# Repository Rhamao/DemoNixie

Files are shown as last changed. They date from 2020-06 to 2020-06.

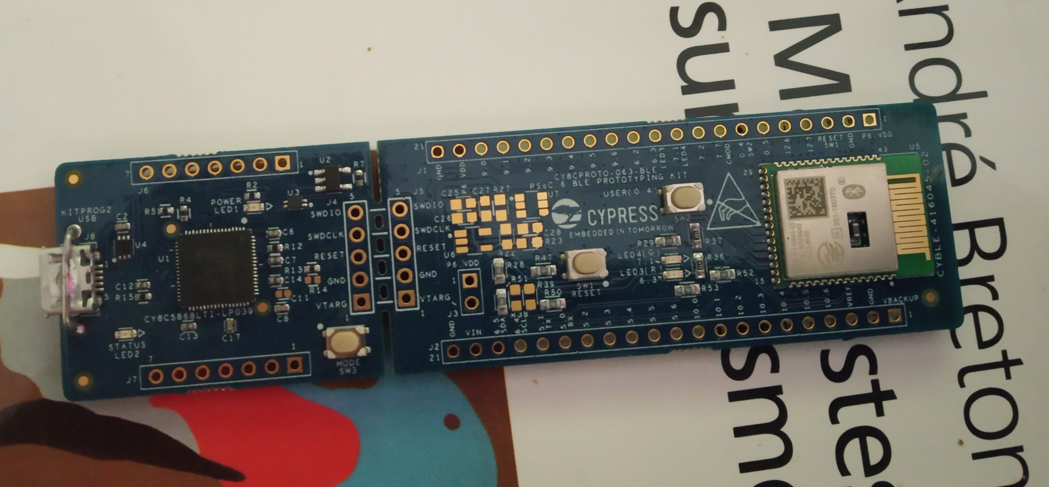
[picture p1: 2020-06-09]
images/CYBLEphoto.jpg

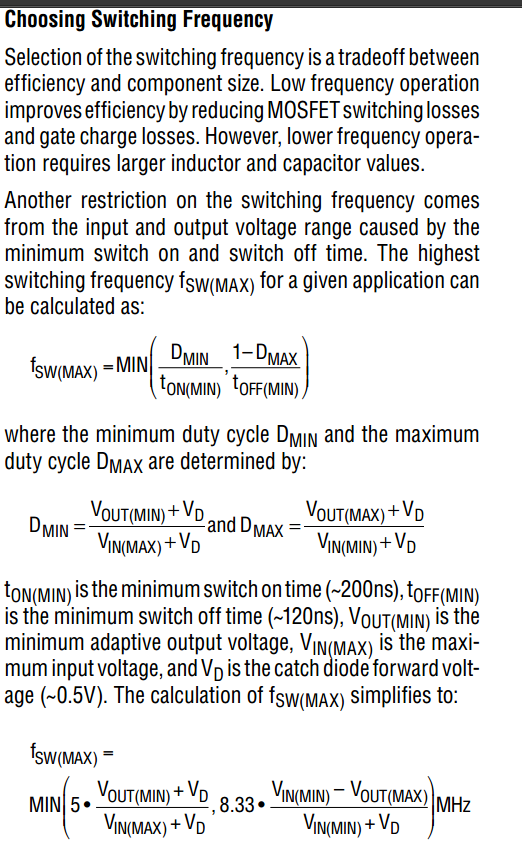
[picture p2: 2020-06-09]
images/Screenshot from 2020-05-18 19-58-37.png

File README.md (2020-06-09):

# DemoNixie
Projet LRPO MECSE de l'IUT de Cachan : Réalisation d'un démonstrateur nixie avec des leds

Branche contenant les documents relatifs à la conception électronique du projet.

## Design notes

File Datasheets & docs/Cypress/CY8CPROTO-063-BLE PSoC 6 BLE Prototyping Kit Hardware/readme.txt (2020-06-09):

--------------------------------------
PCB: 600-60527-01 Rev: 03 
--------------------------------------

PCB Name: CY8CPROTO-063-BLE PSoC 6 BLE PROT0 KIT 

PCB P/N: 600-60527-01 

PCB Rev.: 03 

---------------------------------
----------- PCB Info ------------
---------------------------------

PCB Size: 4.025" x 1.052" 

Layer Count: 2 

Minimum O/L Line Width: 5.010 
Minimum O/L Spacing:    4.990 

Minimum I/L Line Width: N/A 
Minimum I/L Spacing:    N/A 

BGA PIN Pitch: No Devices found. 

Non-BGA Pin Pitch MM (Minimum): 0.400 (Mils: 15.740) 
Non-BGA Reference Designator: U1 / Pins: 63-62 / Pin Count: 71 
Non-BGA Location: (284.7 400.0) - Top Side 

Silkscreen Layers: 2 

---------------------------------
---------- Drill Info -----------
---------------------------------

Number of Different Hole Sizes: 7 

Smallest Hole Size: 0.008 

Largest Hole Size: 0.040 

Hole Count: 433 

Blind-Buried Vias: No 

Slots Found: Yes 

---------------------------------
---------- Extra Info -----------
---------------------------------

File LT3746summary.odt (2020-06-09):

LT3746

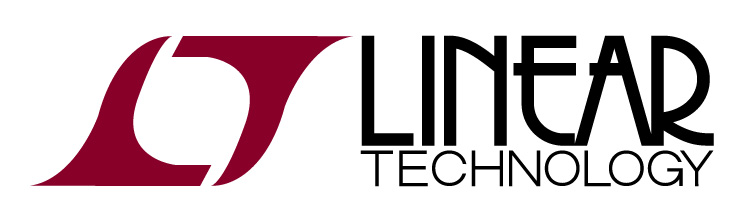
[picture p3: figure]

Features

- Tension d’alimentation de 3V à 5.5V, tension d’alim des LEDs de 6V à 55V
- 32 sorties LEDs indépendantes (10mA to 30mA)
- QFN package
- Registre à décalage de 386 bits

Typical application

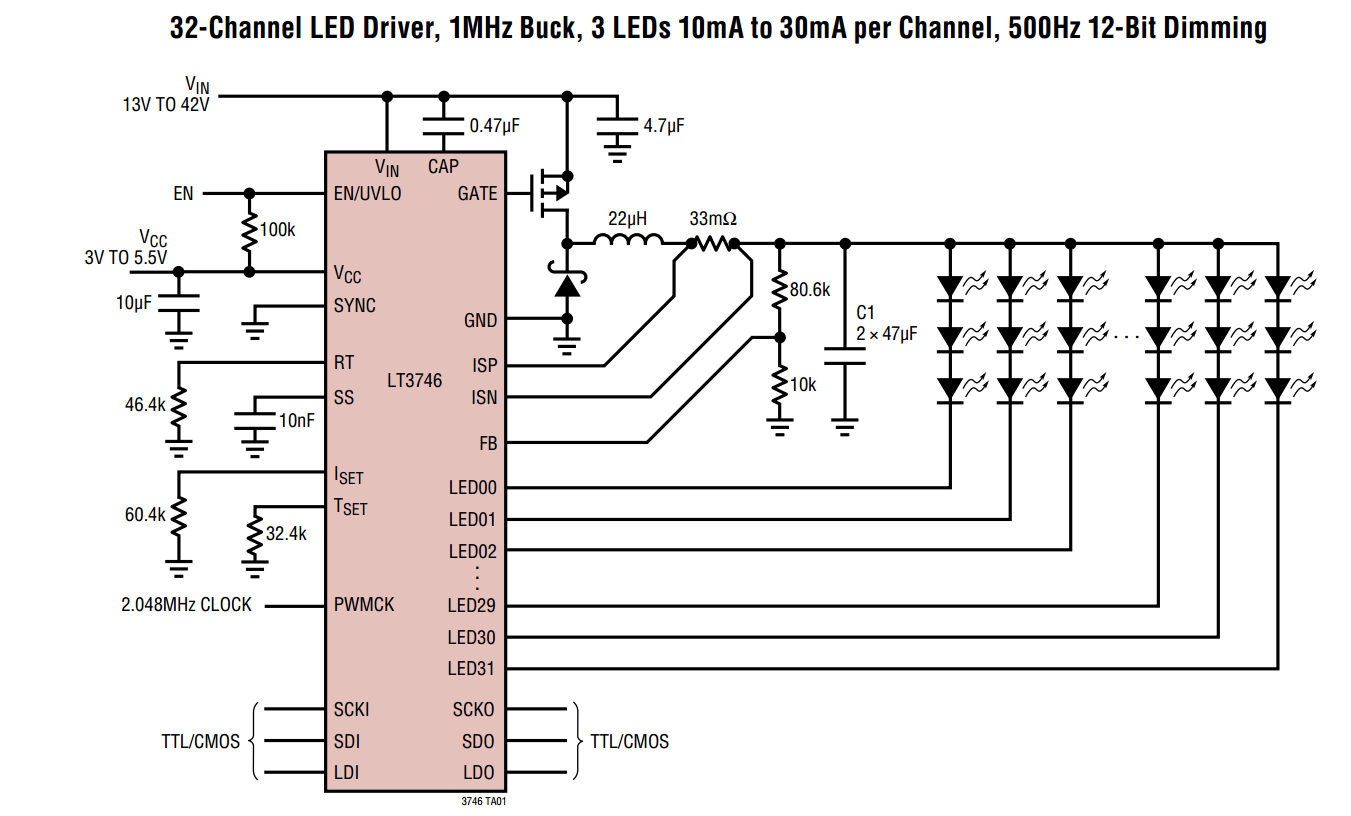
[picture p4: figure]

Pin functions

EN/UVLO : pin 1, enable pin, actif à l’état haut. Connecter à Vcc pour activer le composant, connecter à la masse (ou une tension inférieure à 0.35V) pour le désactiver. Cette pin sert également à définir l’UVLO du composant (seuil de tension d’alim minimum) via un pont diviseur, relié à Vcc. Utile en cas d’utilisation avec une batterie.

LED00 – LED31 : pin 2-17, 30-45. Sorties drivers, connecter aux cathodes des LEDs.

GND : pin 18, 20, 27, 29. Masse.

SCKI : pin19. Entrée clock pour l’interface série TTL/CMOS.

SDI : pin 21. Entrée data pour l’interface série TTL/CMOS.

LDI : pin 22. Entrée latch pour les registres à décalage. Met à jour les sorties en fonction de l’état des registres. Voir partie Opération de la datasheet (page 13).

Vcc : pin 23 : entrée alimentation de la partie logique.

PWMCK : pin 24. Clock pour le timer chargé de créer la PWM (gestion de la luminosité).

LDO : pin 25. Sortie latch pour chaîner un autre LT3746.

SDO : pin 25. Sortie série data pour chaîner un autre LT3746.

LDO : pin 25. Sortie seŕie clock pour chaîner un autre LT3746.

SYNC : pin 46. Une clock (TTL/CMOS) peut être reliée à cette entrée pour synchroniser la fréquence de découpage avec une clock externe. Relier à Vcc ou à la masse si elle n’est pas utiliser.

RT : pin 47, timing resistor. Programme la fréquence de découpage de 200kHz à 1MHz. Voir le Table 2 de la datasheet pour le calcul des valeurs.

SS : pin 48, soft start. Connecter un condensateur à cette entrée pour définir la durée du soft start afin de limiter le courant d’appel à l’allumage.

FB : pin 49, feedback pin. J’ai pas exactement compris comment ça marche, mais il faut la connecter à un pont diviseur entre la source du MOSFET et la masse, afin de réguler la tension d’alim des LEDs. Voir la partie Application Information de la datasheet (p19)

ISN : pin 50. Cette broche est connectée à une des terminaisons de la résistance de mesure du courant, côté négatif.

ISP : pin 51. Cette broche est connectée à l’autre terminaison de la résistance de mesure du courant, côté positif.

CAP : pin 52. Doit être reliée à Vin via un condensateur. J’ai pas exactement compris comment ça marche, mais ça participe à la régulation de la tension d’alim des LEDs. Condensateur près de la broche.

GATE : pin 53. Connecter à la gate du MOSFET avec une trace la plus courte et épaisse possible. Courant crête typique : 1A.

Vin : pin 54, entrée tension LED. Reliée à la masse par un condensateur de filtrage, près du MOSFET (?)

Tset : pin 55. Réglage du seuil de surchauffe. Voir la section Application Information de la datasheet (p19)

Iset : pin 56. Reglage du courant d’alimentation des LEDs via une résistance à la masse. Voir section Application Information (p19) de la datasheet.

Pad sous le composant : masse. Doit être connecté à un plan de masse continue (pas juste sous le pad) afin d’améliorer la dissipation thermique et augmenter la « power capability » du composant.

Interface série

4 Wire Topology :

- LDI, SCKI : global routing (commun a tous les composants)
- SDI : local routing (propre à chaque composant)
- SDI peut etre transmis de composant à composant via la broche SDO
- Peu de composant en cascades (décalage de l’horloge par rapport aux données série)

6 Wire Topology :

- SDI, SCKI, LDI sont envoyés au premier composant de la chaîne, qui les transmet au suivant etc...
- LDO, SCKO, SDO du dernier composant reviennent au uC (pourquoi?)

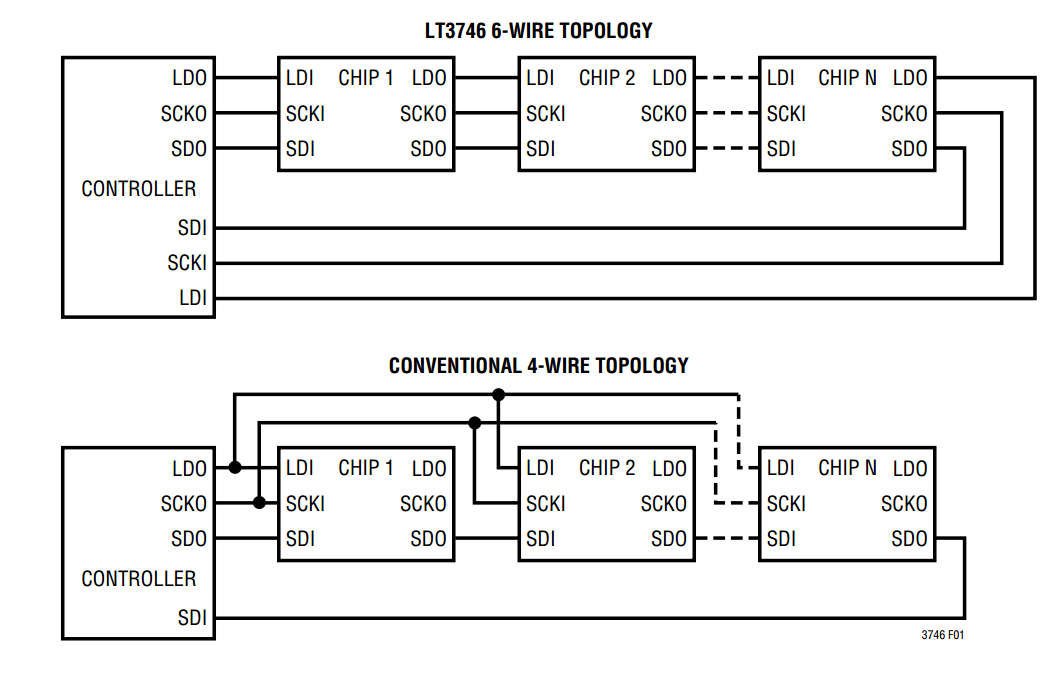
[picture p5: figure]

Les informations sont envoyées au composant sous la forme d’une trame de 386 bits (32 sous-trames de 12 bits + 2 bit de config générale). Cette trame est chargée dans un registre à décalage (SR[0:385]). Une fois les 386 bits envoyés (à chaque front montant de l’horloge sur SCKI), un front montant sur LDI charge les données dans les registres correspondant, et charge une trame de Status dans le registre à décalage de sortie. Si 4 composants sont chainés, il faut envoyer 4 trames de 386 bits. La trame de statut sera reçue avec 4 trames de retard (elle traverse chaque composant en cascade avant de passer au contrôleur).

Configuration analogique

Vout max : RFB1 et RFB2

Le pont diviseur connecté à la broche FB permet de fixer la tension maximale générée par le convertisseur Buck. La datasheet indique que cette tension devrait se situer à 0.5V au dessus de la chute de tension max des séries de LED :

V_{OUT(MAX)} = 0.5 + n times V_{F(MAX)}

Où n × VF(MAX) correspond à la chute de tension totale de la branche de LED avec la chute de tension la plus élevée. La datasheet des LED indique que la chute de tension directe de la LED bleue est de 3.3V max. Cela fait donc une tension VOUT(MAX) = 10.4V.

Les résistances du pont diviseur se calculent comme ceci :

R_FB2 = R_FB1 .( {V_{OUT(MAX)}} over {1.205V} -1)

On choisit une valeur arbitraire pour RFB1, et on détermine RFB2. La datasheet indique que la tolérance des résistance doit être la plus faible possible (1% recommandé), et que de très hautes valeurs de résistances peuvent entraîner des erreurs (RFB1 = 10kΩ recommandé).

Dans notre cas, avec VOUT(MAX) = 10.4V, on obtient ces valeurs : RFB1 = 10kΩ ; RFB2 = 76.307kΩ

Plage de tension d’entrée Vin

La tension d’entrée du convertisseur Buck peut varier entre 6V et 55V. Cependant, elle doit respecter la formule suivante afin de garantir un fonctionnement optimal :

V_{"IN"(MIN)} = V_{OUT(MAX)} + 2V

La tension d’alimentation du convertisseur Buck doit donc être de VIN(MAX) = 12.4V minimum.

Choix du courant nominal des LEDs : RISET

Le courant nominal correspond au courant qui circule dans chaque branche de LEDs lorsque la « dot correction » est programmée à 0x20 (*1). Les LEDs utilisées sont données pour un courant direct recommandé de 5mA (sauf pour la rouge, 10mA). Le courant nominal se calcul ainsi :

I_{LED(NOM)} = {V_ISET} over {R_ISET} * 1000

Avec une valeur RISET = 270kΩ, on a ISET = 4.46mA, ce qui laisse une petite marge de sécurité (le courant peut être ajusté via le registre Dot Correction).

Protection thermique (résistance TTSET)

Cette résistance détermine la tension VTSET. Cette tension est comparée avec une tension générée en interne, VPTAT, qui, lorsqu’elle est supérieure à VTSET, déclenche la protection thermique. Je n’ai pas vraiment compris tous les paramètres qui entre dans l’équation (principalement le calcul de TJ), mais il semblerai qu’une bonne valeur pour VTSET soit de 1V.

V_TSET = 1.205V × {R_{TSET}} over {R_{ISET}}

En choisissant une valeur de 240kΩ pour RTSET, on à VTSET = 1,07V.

Page 24 de la datasheet

Fréquence de découpage

La fréquence de découpage du convertisseur buck peut-être réglée entre 200kHz et 1MHz. Une fréquence basse améliore le rendement du montage en réduisant les pertes induite par le découpage et les cycles charges/décharges de la gate du MOSFET, mais implique de devoir utiliser des composants de plus grandes valeurs, donc plus large (inductance, condensateur) pour le convertisseur.

La résistance qui détermine la fréquence interne doit être choisie pour donner une fréquence environ 20 % en dessous de la fréquence de synchronisation, lorsque celle-ci est utilisée, ce qui est recommandé.

Si on choisit une fréquence de découpage de 500kHz, il faut une fréquence interne aux alentours de 400kHz. La datasheet indique une résistance de 133kΩ pour une fréquence de 400kHz.

Rappel des valeurs choisies

VIN(MIN) = 12.4V

VOUT(MAX) = 10.4V

RISET = 270kΩ

RTSET = 240kΩ

RS = 33mΩ

RFB1 = 10kΩ ; RFB2 = 76.307kΩ

Questions pour Claude

- J’ai un peu du mal à estimer l’importance de la valeur choisie pour la fréquence de découpage du convertisseur buck (configurée via la résistance RT). Est-ce que l’on peut choisir une valeur de 400kHz par exemple en étant sur que cela fonctionnera dans notre application ? Le schéma d’exemple fourni par LT (pas celui de la datasheet, celui qui est sur un PDF a part entière) choisi cette fréquence.

- Il est également question de synchroniser cette fréquence de découpage, mais je ne comprends pas à quoi ça sert. Sur le schéma d’exemple, la synchronisation se fait sur l’horloge de la PWM, ou via le microcontrôleur. Est-on obligé de le faire ? Peut-on sync sur l’horloge PWM sans risque ?

- Je me perd un peu dans le choix des composants pour le convertisseur buck. Est-ce que je peux choisir les même composants que sur le schéma d’exemple. Ça concerne le MOSFET, la diode, l’inductance et quelques condensateurs. Sachant qu’a priori on aura une tension d’alim de 15V (selon les calculs plus haut il faut une tension minimale de 12.4V).

- Quand j’ai choisi d’utiliser ce composant, je pensais que la fin du projet était pour début septembre (la fin de la formation) et qu’on aurait du temps pour approfondir l’usage du truc et faire des prototypes, tests. Finalement la soutenance est le 26 juin… Cela remet en perspective l’usage d’un composant aussi lourd. Il est super et je pense pas que ça soit extrêmement complexe à utiliser, mais disons qu’il y a pas mal de sources d’erreur et que je ne suis pas sur qu’on ai le temps de faire les tests nécessaires. Alors qu’en utilisant une batterie de shift registers on est sur de pas se planter, même si ça complique un peu le routage. En gros, est-ce que tu penses que c’est faisable dans les temps ? J’en doute un peu, et de plus en plus a mesure que je vois le travail qu’il reste à faire.

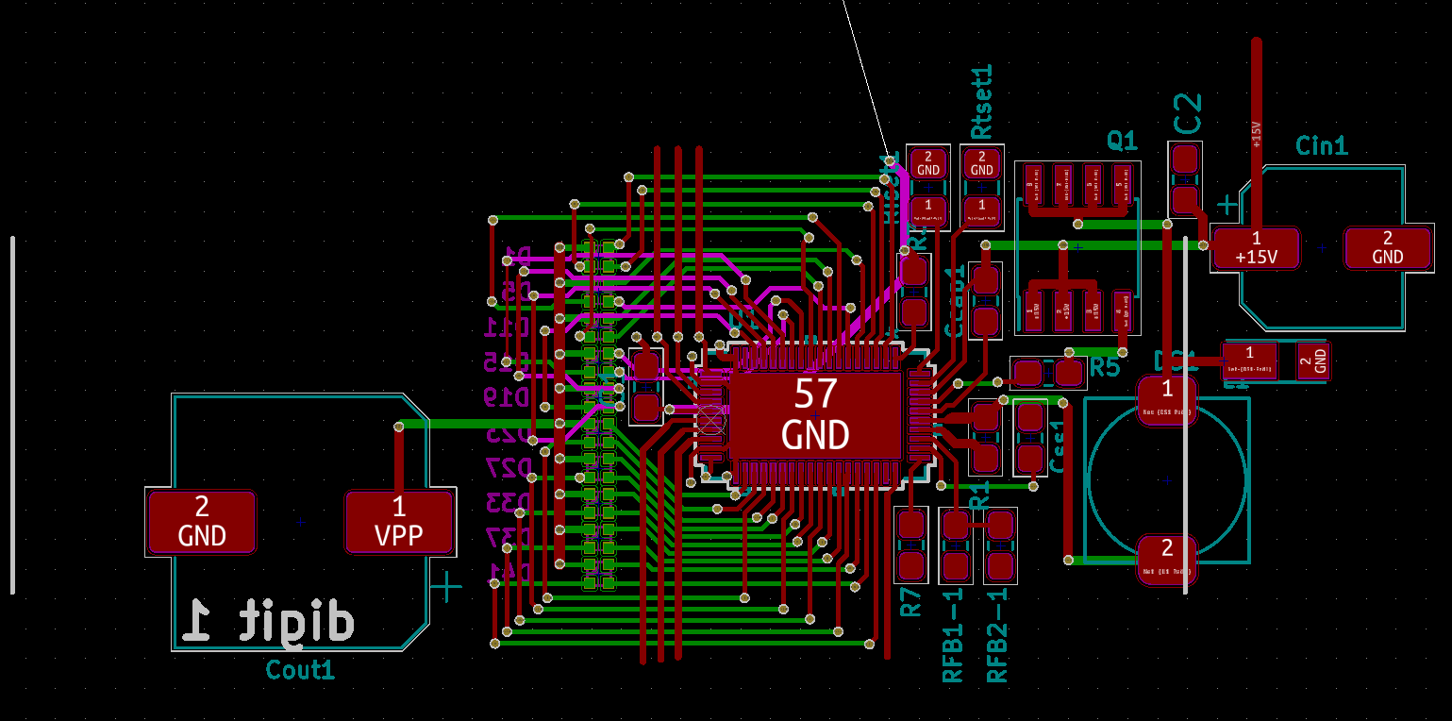
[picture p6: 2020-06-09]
DemoNixie-KiCad/images/Screenshot from 2020-06-03 17-18-07.png

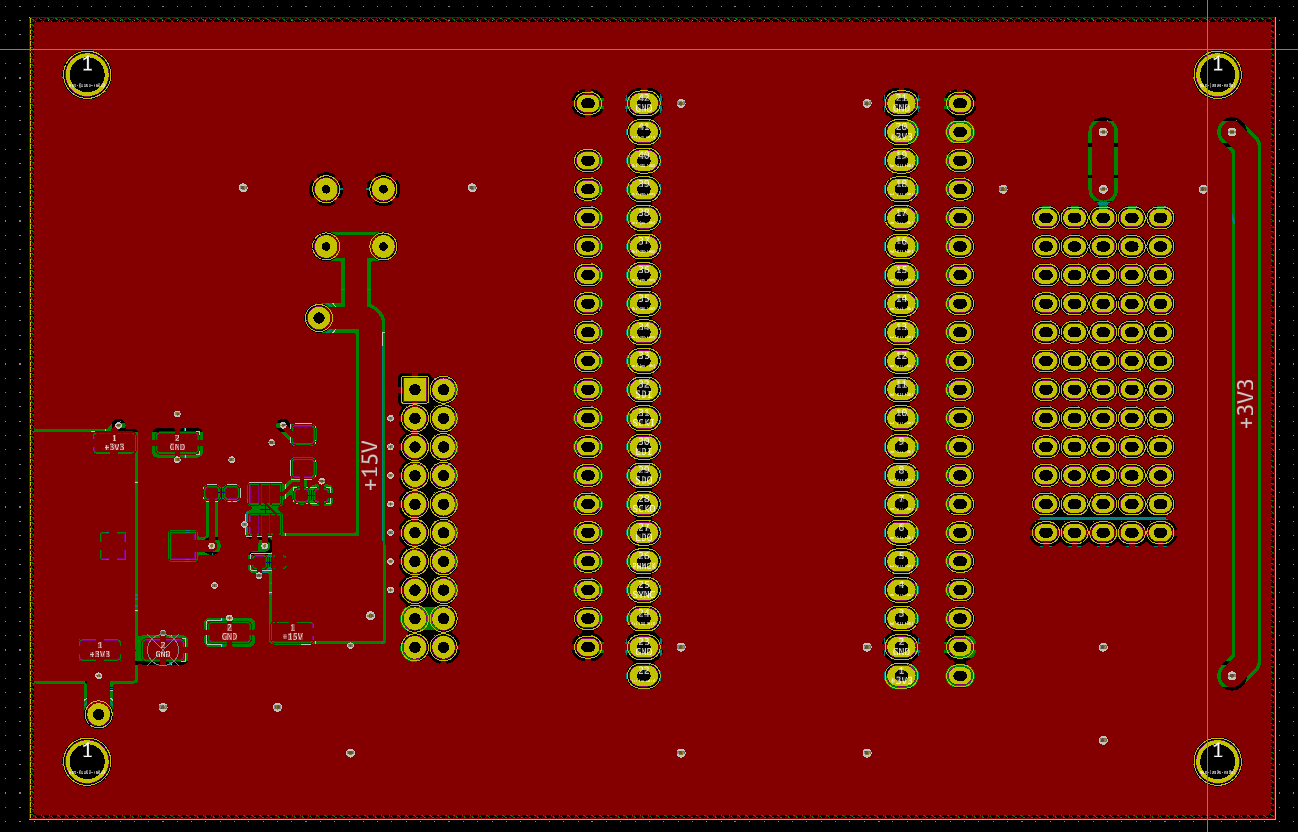
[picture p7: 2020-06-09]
DemoNixieControl-KiCad/images/masseTOP.png

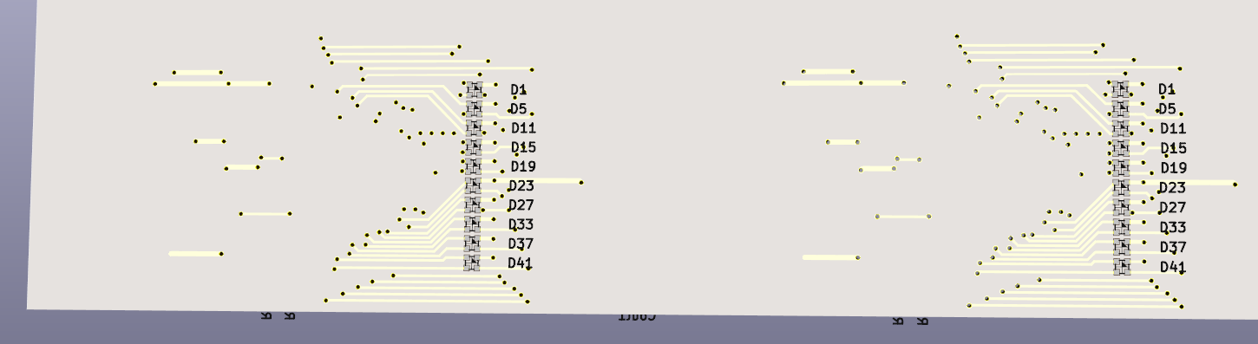
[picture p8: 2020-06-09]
DemoNixie-KiCad/images/Screenshot from 2020-06-03 17-16-41.png

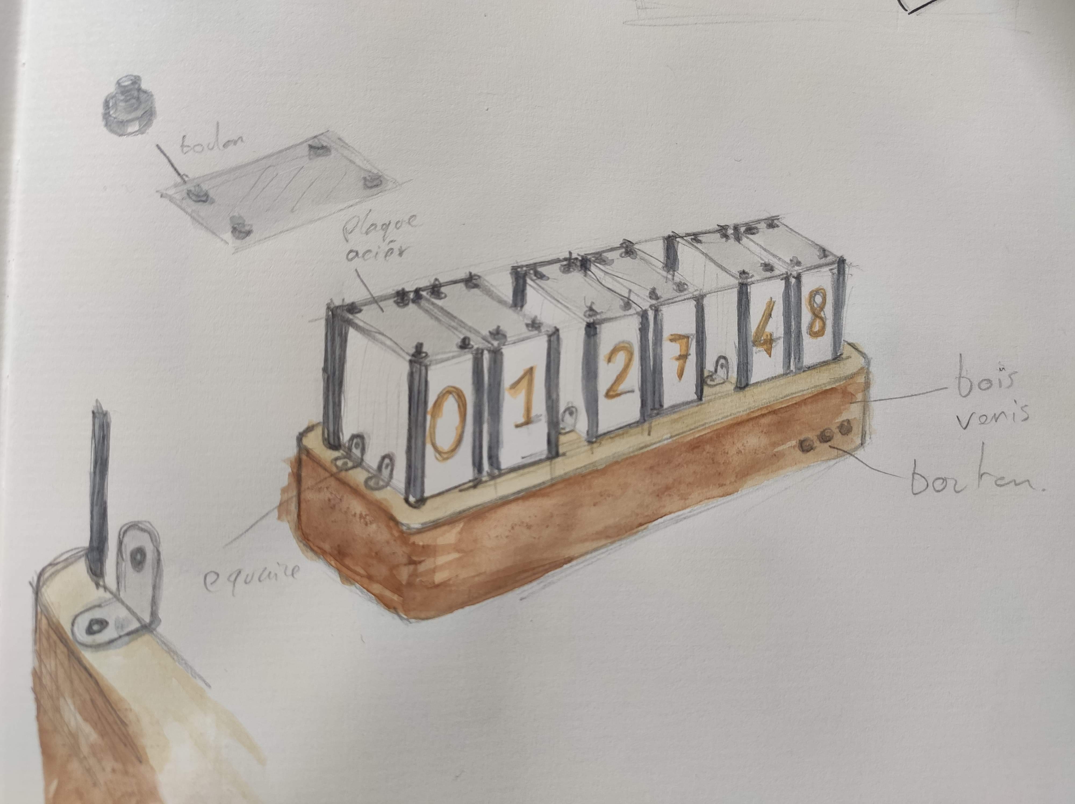
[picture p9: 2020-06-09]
images/dessinFrancois.jpg

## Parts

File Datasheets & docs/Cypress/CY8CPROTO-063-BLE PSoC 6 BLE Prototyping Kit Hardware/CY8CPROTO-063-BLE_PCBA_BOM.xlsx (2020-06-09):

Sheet: Revision History
CYPRESS SEMICONDUCTOR © 2017
Revision | Date | Description | Prepared By | Approved By
1 | 2018-06-02 | Initial BOM update | TARE | RKAD
2 | 2018-08-17 | updated to rev 02 | TARE | RKAD
3 | 2018-09-26 | rev 03 release, changed resistor R36 to 0603 | TARE | RKAD
4 | 2020-01-16 | Updated both WCO load caps C36,C37 to 22pF | TARE | RKAD
 |  |  |  |  | a

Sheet: PCBA BOM
 |  |  |  |  | CYPRESS SEMICONDUCTOR © 2017
 |  |  |  |  | TITLE | CY8CPROTO-063-BLE PSoC 6 BLE Prototyping Kit
 |  |  |  |  | PCBA Number & Revision | 121-60527-01 | Rev 03
 |  |  |  |  | Schematics Number & Revision | 630-60527-01 | Rev 04
 |  |  |  |  | DATE | 2020-01-16
 |  |  |  |  | BOM REVISION | Rev 04
 |  |  |  |  | ROHS Compliance | Required
 |  |  |  |  | UL Compliance | Required
# | Cypress Part # | Qty | Reference | Value | Description | Manufacturer | Mfr Part # | Alternate Manufacturer | Alternate Mfr Part #
1 | 510-60089-01 | 1 | C1 | 10nF | CAP, CER, 0.01uF, 10%, X7R, 50V, 0402 | Murata | GRM155R71H103KA88D
2 | 510-60247-01 | 11 | C2,C4,C6,C8,C10,C15,C17,C19,C21,C23,C38 | 0.1uF | CAP, CER, 0.1UF, 10%, X7R, 16V, 0402 | Samsung Electro-Mechanics America, Inc. | CL05B104KO5NNNC
3 | 510-60203-01 | 10 | C3,C5,C7,C9,C12,C13,C14,C16,C18,C20 | 1.0 uF | CAP, CER, 1UF, 10%, 10V, X5R, 0402 | Taiyo Yuden | LMK105BJ105KV-F
4 | 510-60058-01 | 2 | C22,C24 | 4.7uF | CAP, CER, 4.7uF, 10%, X5R, 16V, 0603 | Murata | GRM188R61C475KAAJD
5 | 510-60180-01 | 1 | C29 | 10uF | CAP, CER, 10uF, 20%, X5R, 25V, 0603 | Murata | GRM188R61E106MA73D
6 | 510-60190-01 | 1 | C32 | 2.2nF | CAP CER 2200PF 50V NP0 0805 | Murata | GRM2165C1H222JA01D
7 | 510-60716-01 | 2 | C36,C37 | 22pF | CAP, CER, 22PF, 5%, COG, 50V, 0402 | Yageo | CC0402JRNPO9BN220
8 | 751-60031-01 | 1 | JMP1 | USB_Hold | WIRE, WIRE BUS BAR 1000' LONG, THICKNESS 22 AWG | Alpha Wire | 298SV001
9 | 720-60080-01 | 1 | J8 | 10118194-0001LF | CONN, RCPT, STD, MICRO, USB, TYPE B | FCI | 10118194-0001LF
10 | 534-60113-01 | 2 | LED1,LED2 | AMBER LED | LED, YELLOW, CLEAR, 0603 | Lite-On Inc. | LTST-C191KSKT
11 | 534-60065-01 | 1 | LED3 | RED LED | LED, RED, CLEAR, 0603 | Lite-On Inc. | LTST-C190CKT
12 | 534-60054-01 | 1 | LED4 | GREEN LED | LED, GREEN, CLEAR, 0603 | Lite-On Inc | LTST-C190KGKT
13 | 500-60075-01 | 1 | R1 | 100K | RES, 100K OHM, 5%, 100PPM, 1/16W, 0402 | Yageo | RC0402JR-07100KL
14 | 500-60047-01 | 2 | R2,R17 | 2.2K | RES, 2.2K OHM, 5%, 200PPM, 1/10W, 0402 | Panasonic | ERJ-2GEJ222X
15 | 500-60108-01 | 11 | R3,R28,R29,R31,R47,R48,R49,R50,R51,R52,R53 | 0ohm | RES, 0 OHM, 1/10W, 0603, SMD | Rohm Semiconductor | MCR03EZPJ000
16 | 500-60445-01 | 2 | R4,R15 | 15K | RES, 15K OHM, 1/10W, 5%, 0402, SMD | Panasonic | ERJ-2GEJ153X
17 | 500-60446-01 | 2 | R5,R16 | 30K | RES, 30K OHM, 1/10W, 5%, 0402, SMD | Panasonic | ERJ-2GEJ303X
18 | 500-60925-01 | 1 | R6 | 180K | RES, 180K OHM, 1%, 100PPM, 1/10W, 0603 | Yageo | RC0603FR-07180KL
19 | 500-60926-01 | 1 | R7 | 57.6K | RES, 57.6K OHM, 1%, 100PPM, 1/16W, 0402, SMD | Yageo | RC0402FR-0757K6L
20 | 500-60927-01 | 1 | R8 | 383K | RES, 383K OHM, 1%, 100PPM, 1/16W, 0402 | Yageo | RC0402FR-07383KL
21 | 500-60075-01 | 1 | R12 | 100K | RES, 100K OHM, 5%, 200PPM, 1/10W, 0402 | Panasonic | ERJ-2GEJ104X
22 | 500-60149-01 | 1 | R13 | 49.9K | RES, 49.9K OHM, 1%, 100PPM, 1/10W, 0402, SMD | Panasonic | ERJ-2RKF4992X
23 | 500-60085-01 | 2 | R18,R19 | 22E | RES, 22 OHM, 1%, 100PPM, 1/16W, 0402 | Yageo | RC0402FR-0722RL
24 | 500-60095-01 | 2 | R20,R21 | 4.7K | RES, 4.7K OHM, 5%, 100PPM, 1/16W, 0402 | Yageo | RC0402JR-074K7L
25 | 500-60045-01 | 1 | R33 | 10K | RES, 10K OHM, 1/10W, 5%, 0603, SMD | Yageo | RC0603JR-0710KL
26 | 500-60589-01 | 1 | R36 | 470ohm | RES, 470 OHM, 5%, 1/10W, 0603, SMD | Panasonic | ERJ-3GEYJ474V
27 | 500-60129-01 | 1 | R37 | 330ohm | RES, 330 OHM, 5%, 200PPM, 1/10W, 0603 | Bourns Inc. | CR0603-JW-331GLF
28 | 500-60929-01 | 1 | R40 | 120K | RES, 120K OHM, 1%, 100PPM, 1/16W, 0402 | Yageo | RC0402FR-07120KL
29 | 770-60033-01 | 3 | SW1,SW2,SW3 | SKRPACE010 | SW, TACTILE SWITCH, 4.2x3.2x2.5MM, 260GF | ALPS ELECTRIC CO.,LTD | SKRPACE010
30 | CY8C5868LTI-LP039 | 1 | U1 | CY8C5868LTI-LP039 | IC, CYPRESS, PSoC 5LP, RAM 64KB, 32 Bit MCU, 68PIN, QFN | Cypress Semiconductor | CY8C5868LTI-LP039
31 | 450-60294-01 | 1 | U2 | AP7365-WG-7 | IC, REG, LDO, 600mA, ADJ, SOT25-5 | Diodes Incorporated | AP7365-WG-7
32 | 450-60257-01 | 1 | U3 | SiP32408 | IC, LOAD SWITCH, 3.5A, TDFN4 | Vishay Siliconix | SIP32408DNP-T1-GE4
33 | 530-60071-01 | 1 | U4 | PUSBM12VX4-TL,115 | TVS DIODE, 5.5VWM, 12VC, 6DFN1616 | NXP Semiconductors | PUSBM12VX4-TL,115
34 | CYBLE-416045-02 | 1 | U5 | CYBLE-416045-02 | BLE CHIP | Cypress Semiconductor | CYBLE-416045-02
35 | 455-60032-01 | 1 | U8 | AP2331TDW-7 | IC, CURRENT SW, 400mA, SC-59 | Diodes Incorporated | AP2331TDW-7
36 | 542-60016-01 | 1 | Y2 | 32.768KHz | CRYSTAL, 32.768KHZ, 12.5PF, SMD | ECS Inc | ECS-.327-12.5-34B-TR
NO LOAD
37 | 510-60203-01 | 1 | C11 | 1.0 uF | CAP, CER, 1UF, 10%, 10V, X5R, 0402 | Taiyo Yuden | LMK105BJ105KV-F
38 | 510-60284-01 | 2 | C25,C27 | 4.7uF | CAP, CER, 4.7uF, 10%, 10V, X5R, 0603 | Samsung Electro-Mechanics | CL10A475KP8NNNC
39 | 510-60279-01 | 2 | C26,C28 | 0.1uF | CAP, CER, 0.1UF, 10%, X7R, 16V, 0603 | Murata | GCM188R71C104KA37D
40 | 510-60417-01 | 2 | C30,C31 | 0.47nF | CAP CER 470PF 50V 5% NP0 0805 | Murata Electronics | GRM2165C1H471JA01D
41 | 510-60714-01 | 2 | C34,C35 | 10pF | CAP, CER, 10pF, 50V, ±0.5pF, C0G, NP0, 0603 | TDK Corporation | CGA3E2C0G1H100D080AA
42 |  | 2 | J1,J2 | CON 21x1 | CONN HEADER VERT 21POS .100 | Harwin Inc. | M20-9772146
43 | 710-60032-01 | 1 | J3 | HDR2 | CONN HEADER VERT 2POS .100 30AU | 3M | 961102-6404-AR
44 | 720-60038-01 | 2 | J4,J5 | CON 5x1 | CONN HEADER VERT 5POS .100 TIN | Molex | 22-28-4050
45 |  | 2 | J6,J7 | CON 7x1 | CONN HEADER FEMALE 7POS .1" TIN | Sullins Connector Solutions | PPTC071LFBN-RC
46 | 500-60108-01 | 5 | R9,R27,R32,R44,R46 | 0ohm | RES, 0 OHM, 1/10W, 0603, SMD | Rohm Semiconductor | MCR03EZPJ000
47 | 500-60149-01 | 1 | R14 | 49.9K | RES, 49.9K OHM, 1%, 100PPM, 1/10W, 0402, SMD | Panasonic | ERJ-2RKF4992X
48 | 500-60925-01 | 1 | R22 | 180K | RES, 180K OHM, 1%, 100PPM, 1/10W, 0603 | Yageo | RC0603FR-07180KL
49 | 500-60649-01 | 1 | R23 | 57.6K | RES, 57.6K OHM, 1%, 100PPM, 1/10W, 0603, SMD | Panasonic Electronic Components | ERJ-3EKF5762V
50 | 500-60045-01 | 1 | R30 | 10K | RES, 10K OHM, 1/10W, 5%, 0603, SMD | Yageo | RC0603JR-0710KL
51 | 500-60217-01 | 2 | R38,R39 | 4.7K | RES, 4.7K OHM, 5%, 100PPM, 1/16W, 0402 | Yageo | RC0603JR-074K7L
52 | 500-60108-01 | 1 | R41 | 0ohm | RES SMD 0.0OHM JUMPER 1/10W 0603 | Rohm Semiconductor | MCR03EZPJ000
53 |  | 1 | R45 | 10K | RES, 10K OHM, 5%, 1/10W, 0603, SMD | Vishay Dale | CRCW060310K0JNEAC
54 |  | 3 | TP1,TP2,TP3 | TP_SMD | TESTPOINT, SMD, 40MILS, ROUND | -NA- | -NA-
55 | 450-60294-01 | 1 | U6 | AP7365-WG-7 | IC, REG, LDO, 600mA, ADJ, SOT25-5 | Diodes Incorporated | AP7365-WG-7
56 |  | 1 | U7 | SIP32510DT-T1-GE3 | IC, LOAD SWITCH, 3.5A, SOT23-6 | Vishay Siliconix | SIP32510DT-T1-GE3
57 |  | 1 | Y1 | 24MHz | CRYSTAL, 24MHZ, 8pF, SMD | ECS Inc | ECS-240-8-37CKM
ACCESSORIES
58 | 121-60527-01 | 1 | ACC1 | 121-60527-01 | ASSY, PCBA, CY8CPROTO-063-BLE PSoC 6 BLE Prototyping Kit | Cypress Approved CM | -NA-
59 | 600-60527-01 | 1 | ACC2 | 600-60527-01 | PCB, BARE, CY8CPROTO-063-BLE PSoC 6 BLE Prototyping Kit | Cypress Approved CM | -NA-
60 | 610-60527-01 | 1 | ACC3 | 610-60527-01 | DRW, FABRICATION DRAWING, CY8CPROTO-063-BLE PSoC 6 BLE Prototyping Kit | -NA- | -NA-
61 | 620-60527-01 | 1 | ACC4 | 620-60527-01 | DRW, ASSEMBLY DRAWING, CY8CPROTO-063-BLE PSoC 6 BLE Prototyping Kit | -NA- | -NA-
62 | 630-60527-01 | 1 | ACC5 | 630-60527-01 | DRW, SCHEMATIC DRAWING, CY8CPROTO-063-BLE PSoC 6 BLE Prototyping Kit | -NA- | -NA-
63 | 899-60120-01 | 1 | ACC6 | LBL PCA Label | LBL, PCA Label, Vendor Code, Datecode, Serial Number (YYWWVVXXXXX) | JETech | 899-60120-01
64 | 700-60144-01 | 4 | ACC7,ACC8,ACC9,ACC10 | RBS-40 | HW, BUMPON, CYLIN, 0.25", DIA, BLK | Essentra Components | RBS-40
 |  |  |  |  |  |  |  |  |  | No Load
 |  |  |  |  |  |  |  |  |  | No Load
 |  |  |  |  |  |  |  |  |  | No Load
 |  |  |  |  |  |  |  |  |  | No Load
 |  |  |  |  |  |  |  |  |  | No Load
 |  |  |  |  |  |  |  |  |  | No Load
 |  |  |  |  |  |  |  |  |  | No Load
 |  |  |  |  |  |  |  |  |  | No Load
 |  |  |  |  |  |  |  |  |  | No Load
 |  |  |  |  |  |  |  |  |  | No Load
 |  |  |  |  |  |  |  |  |  | No Load
 |  |  |  |  |  |  |  |  |  | No Load
 |  |  |  |  |  |  |  |  |  | No Load
 |  |  |  |  |  |  |  |  |  | No Load
 |  |  |  |  |  |  |  |  |  | No Load
 |  |  |  |  |  |  |  |  |  | No Load
 |  |  |  |  |  |  |  |  |  | No Load
 |  |  |  |  |  |  |  |  |  | No Load
 |  |  |  |  |  |  |  |  |  | No Load
 |  |  |  |  |  |  |  |  |  | No Load
 |  |  |  |  |  |  |  |  |  | No Load

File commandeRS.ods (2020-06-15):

Composant | Ref RS | Quantité | Prix unitaire | Prix total
R 10k 1% 0603 | 721-7422 | 10 | 0.056 | 0.56
R 33k2 1% 0.25W 1206 | 679-2064 | 50 | 0.091 | 4.55
R 76k8 1% 0603 | 106-2935 | 100 | 0.012 | 1.2
R 240k 1% 0603 | 862-6868 | 100 | 0.029 | 2.9
R 270k 1% 0.2W 0603 | 179-1438 | 500 | 0.051 | 25.5
R 130k 1% 0603 | 862-6767 | 100 | 0.031 | 3.1
R 6.2 1% 0603 | 722-1153 | 5 | 0.07 | 0.35
R 33m 1% 1W 0603 | 134-6394 | 20 | 0.291 | 5.82
C 10n 50V 0603 | 264-4595 | 25 | 0.032 | 0.8
C 470n 50V 0603 | 788-3004 | 50 | 0.078 | 3.9
C 2.2u 50V 0603 | 788-3048 | 10 | 0.309 | 3.09
C 220u 50V 11x10.3x16.5mm | 181-2287 | 5 | 1.96 | 9.8
C 22u 50V 6.3x5.35mm | 839-1874 | 25 | 0.241 | 6.025
C 10u 50V 5.5x6.15mm | 838-7857 | 25 | 0.245 | 6.125
C 100n 50V 0603 | 788-2985 | 50 | 0.078 | 3.9
Diode DFLS160-7 | 708-2282 | 25 | 0.324 | 8.1
MOSFET SI9407BDY-T1 | 818-1444 | 20 | 0.712 | 14.24
L 15u TDK SLF7045T-150M1R1 | 604-4983 | 10 | 0.715 | 7.15
L 2.2u Wurth 744778002 | 744-4915 | 5 | 2.108 | 10.54
Regulateur TPS563200 | 914-3109 | 5 | 1.194 | 5.97
Connecteur M 20 broches | 625-7296 | 2 | 2.33 | 4.66
Connecteur F 20 broches | 454-2479 | 2 | 1.43 | 2.86
Alim découpage 15V-1A | 161-8211 | 1 | 10.76 | 10.76
TOTAL |  |  |  | 141.9

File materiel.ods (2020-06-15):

LED
Composant | Référence | Ref RS | Qté | Nom. | Description
LT3746 | LT3746 |  | 4 |  | LED driver
R 10k |  | 721-7422 | 8 | R3, R4, R11, R12, RFB1-1, RFB1-2, RFB1-3, RFB1-4 | EN/UVLO – RFB1
R 76k3 |  | 106-2935 | 4 | RFB2-1, RFB2-2, RFB2-3, RFB2-4 | RFB2
R 240k |  | 862-6868 | 4 | Rtset1, Rtset2, Rtset3, Rtset4 | Rtset
R270k |  | 176-4951 | 4 | Riset1, Riset2, Riset3, Riset4 | Riset
R 133k |  | 862-6767 | 4 | R7, R8, R15, R16 | Rt
R 5.1 |  | 722-1153 | 4 | R5, R6, R13, R14 | res gate MOSFET
R 33m |  | 134-6394 | 4 | R1, R2, R9, R10 | Rsense (fort courant)
C 10n |  | 264-4595 | 4 | Css1, Css2, Css3, Css4 | Css
C 470n |  | 788-3004 | 4 | Ccap1, Ccap2, Ccap3, Ccap4 | Ccap
C 220u |  | 181-2287 | 4 | Cout1, Cout2, Cout3, Cout4 | Cout low ESR, tantal ou alu
C 22u |  | 839-1874 | 4 | Cin1, Cin2, Cin3, Cin4 | Cin
C 2.2u |  | 788-3048 | 4 | C2, C4, C7, C9 | decouplage Vin
C 10u |  | 838-7857 | 1 | C5 | decouplage Vcc connecteur
C 100n |  | 788-2985 | 8 | C1, C2, C3, C4, C6, C7, C8, C9 | decouplage Vcc, découplage Vin
D | DiodeZetex DFLS160 | 708-2282 | 4 | DS1, DS2, DS3, DS4 | diode buck
MOSFET P | Vishay SI9407BDY | 818-1444 | 4 | Q1, Q2, Q3, Q4 | MOSFET buck
L | TDK SLF7045T-150M1R1-PF | 604-4983 | 4 | L1, L2, L3, L4 | Inductance Buck
Connecteur M |  | 625-7296 | 2 |  | Pas 1,27, 20 broches en deux lignes
Connecteur F |  | 454-2479 | 2
CONTROL
Regulateur | TPS563200DDCT | 914-3109 | 1
R 33k |  | 679-2064 | 1
L | Wurth 744778002 | 744-4915P | 1

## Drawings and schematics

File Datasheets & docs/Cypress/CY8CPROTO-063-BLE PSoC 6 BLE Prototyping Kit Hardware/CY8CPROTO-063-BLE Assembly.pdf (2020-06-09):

# ART FILM - assy_t

1

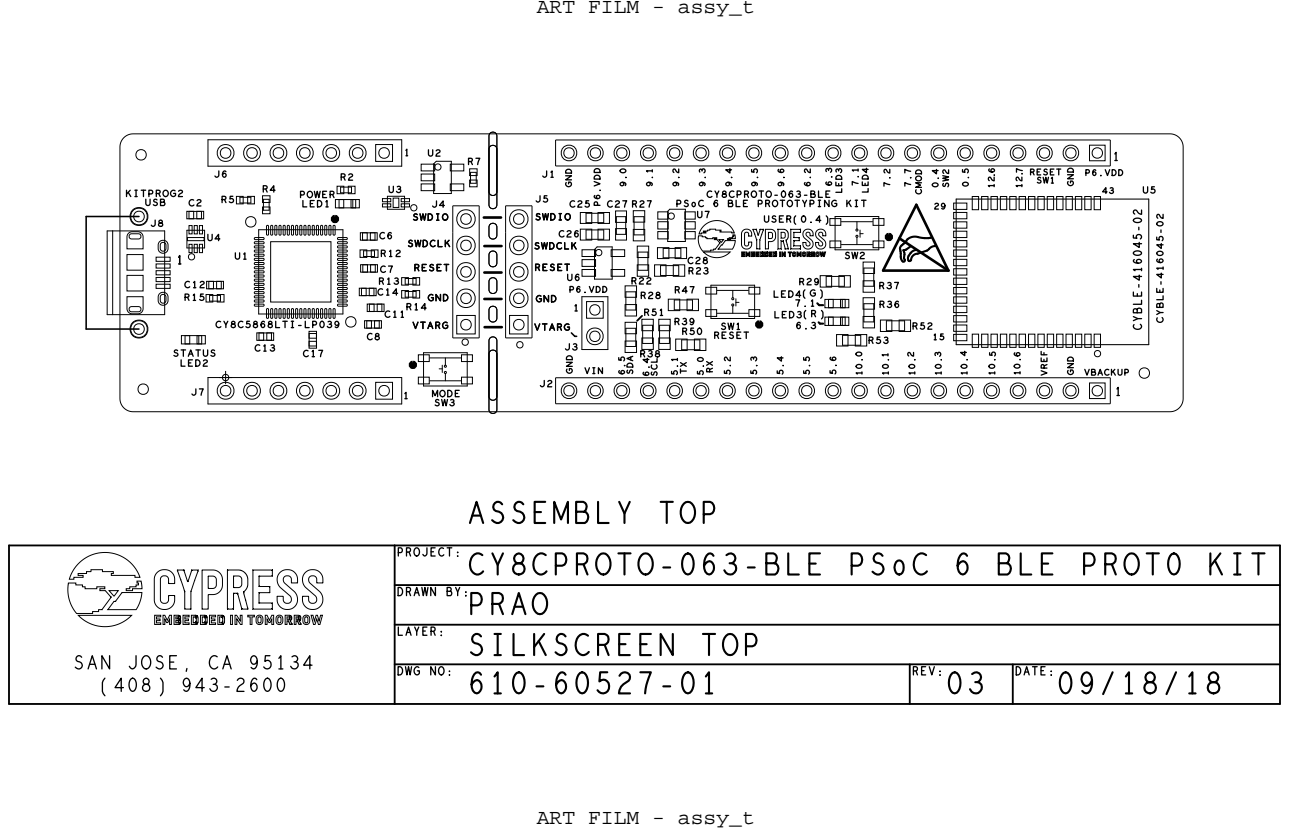
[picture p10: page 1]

LAYER: SILKSCREEN TOP
DWG NO: 610-60527-01 | 03 | 09/18/18

# ART FILM - assy_b

# R30 LED4

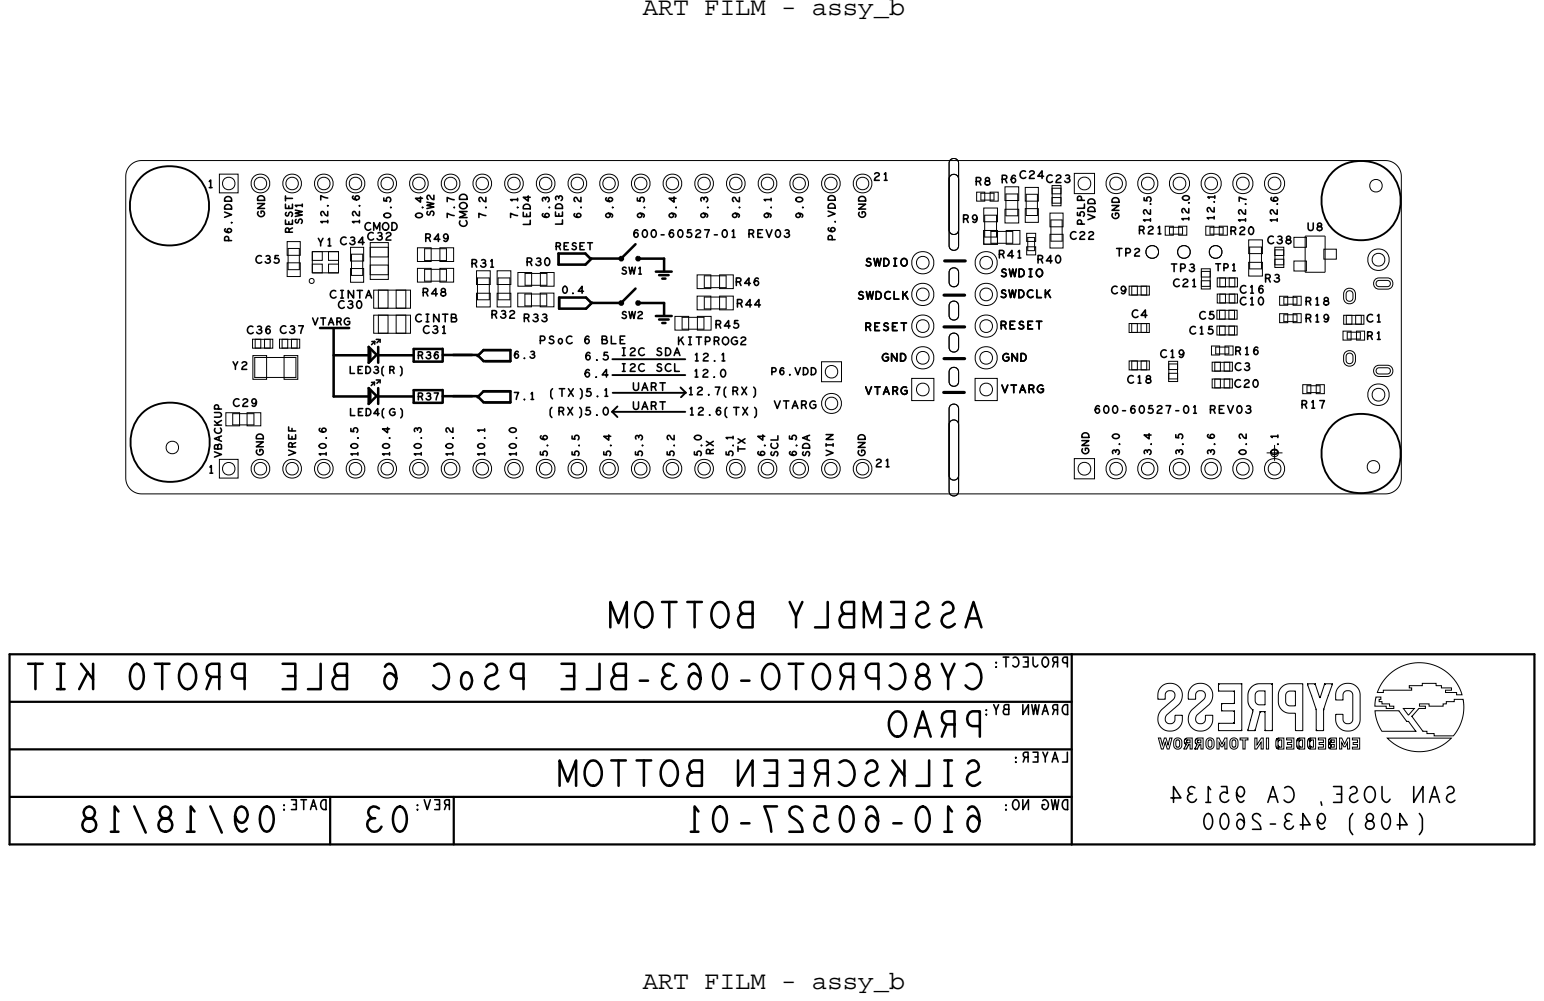
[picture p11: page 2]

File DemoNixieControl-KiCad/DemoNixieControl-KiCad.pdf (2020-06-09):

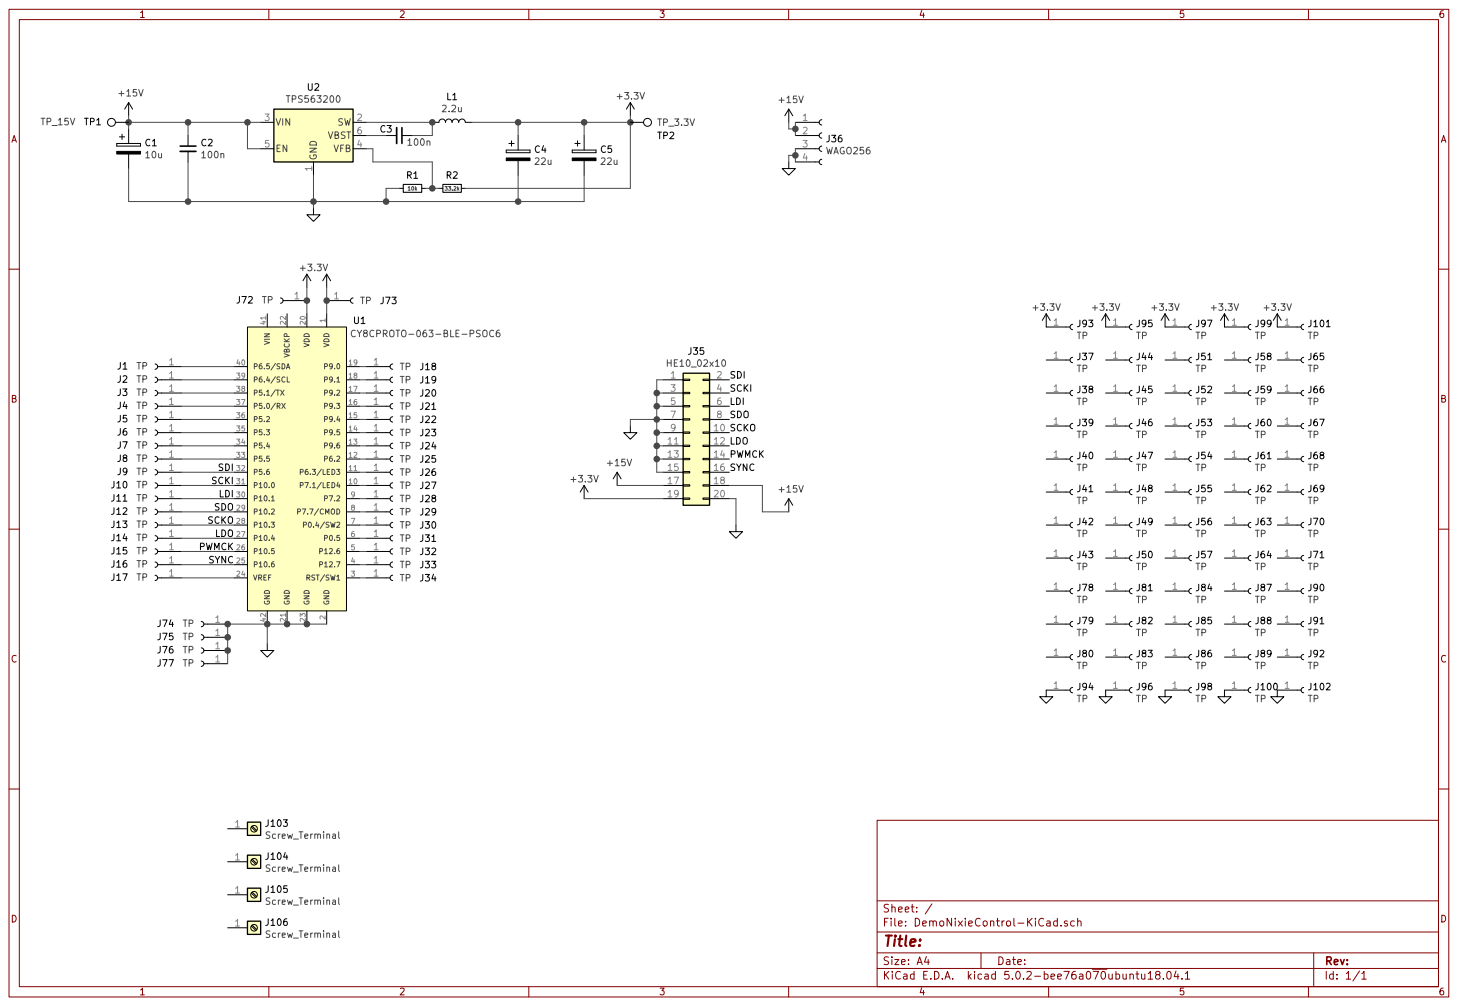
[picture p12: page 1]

1 SW 2 VIN 3 VFB 4 EN 5 VBST 6 U2 TPS563200 C1

2 VDD 20 GND 21 VBCKP 22 GND 23 VREF 24 P10.6 25 P10.5 26 P10.4 27 P10.3 28 P10.2 29 RST/SW1 3 P10.1 30 P10.0 31 P5.6 32 P5.5 33 P5.4 34 P5.3 35 P5.2 36 P5.0/RX 37 P5.1/TX 38 P6.4/SCL 39 P12.7 4 P6.5/SDA 40 VIN 41 GND 42 P12.6 5 P0.5 6 P0.4/SW2 7 P7.7/CMOD 8 P7.2 9U1CY8CPROTO-063-BLE-PSOC6 +3.3V

1 P7.1/LED4 10 P6.3/LED3 11 P6.2 12 P9.6 13 P9.5 14 P9.4 15 P9.3 16 P9.2 17 P9.1 18 P9.0 19 GND
Id: 1/1 Title: File: DemoNixieControl-KiCad.sch Sheet: / VDD

SDI SCKI LDI SDO

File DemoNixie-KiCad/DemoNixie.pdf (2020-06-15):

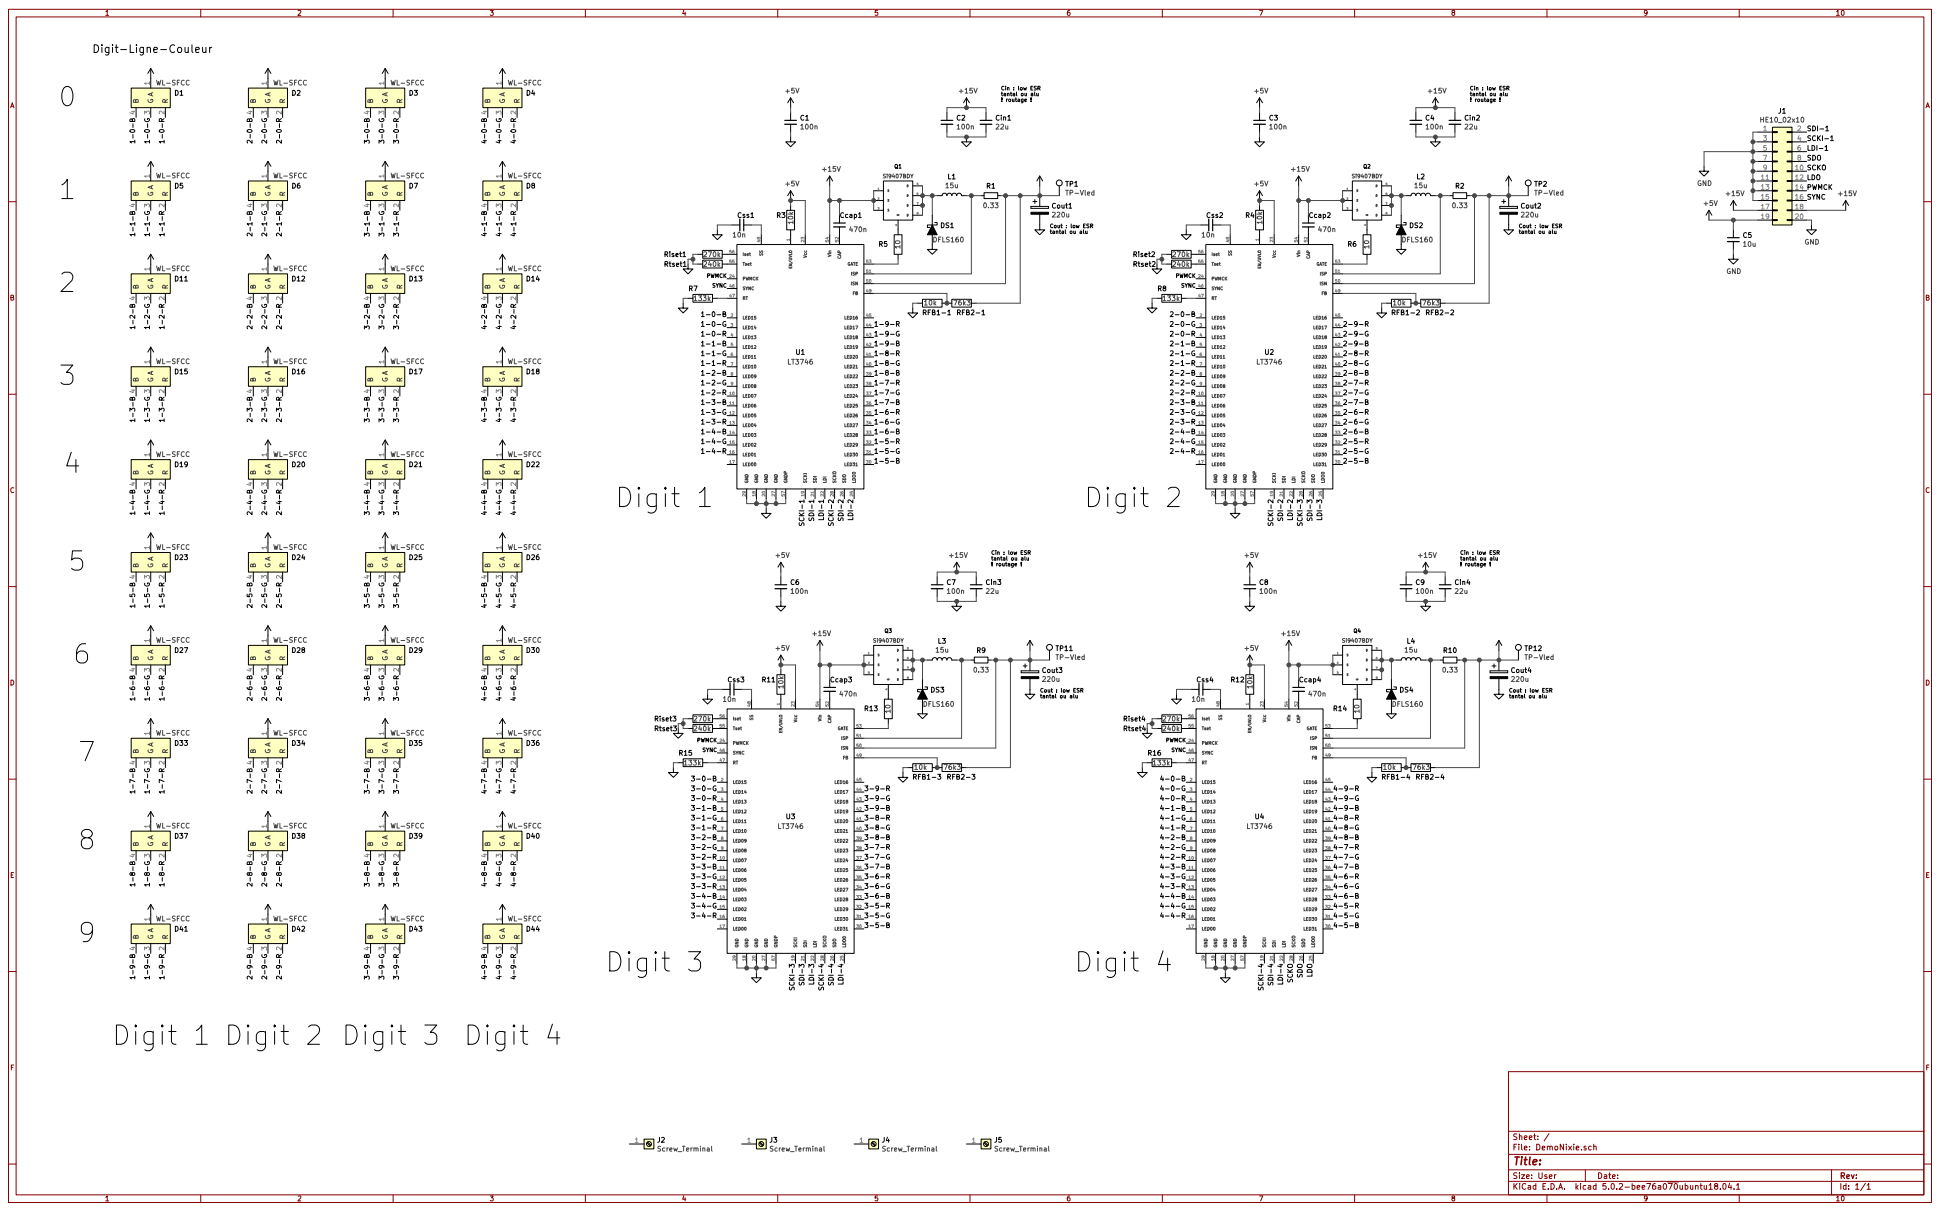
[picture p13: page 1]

Id: 1/1 Title: File: DemoNixie.sch Sheet: /

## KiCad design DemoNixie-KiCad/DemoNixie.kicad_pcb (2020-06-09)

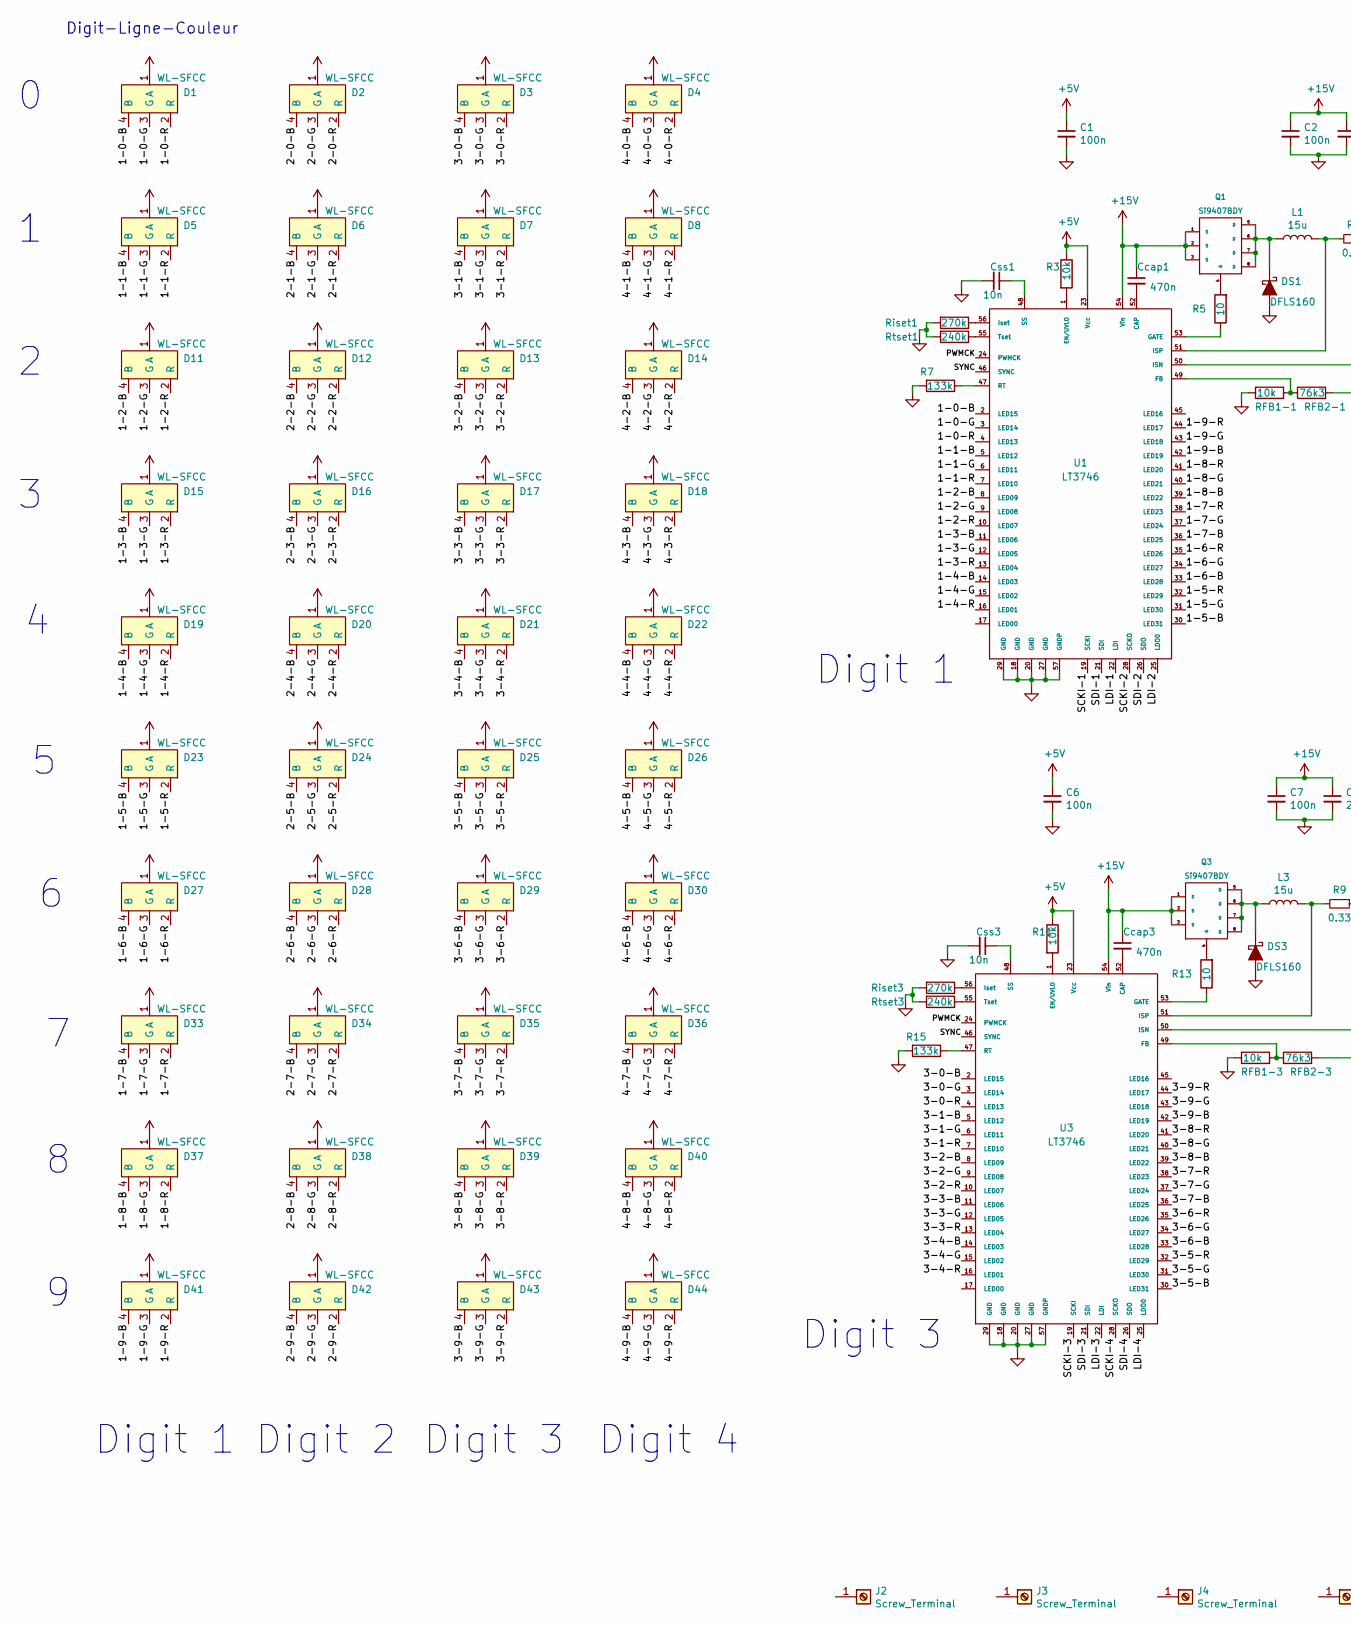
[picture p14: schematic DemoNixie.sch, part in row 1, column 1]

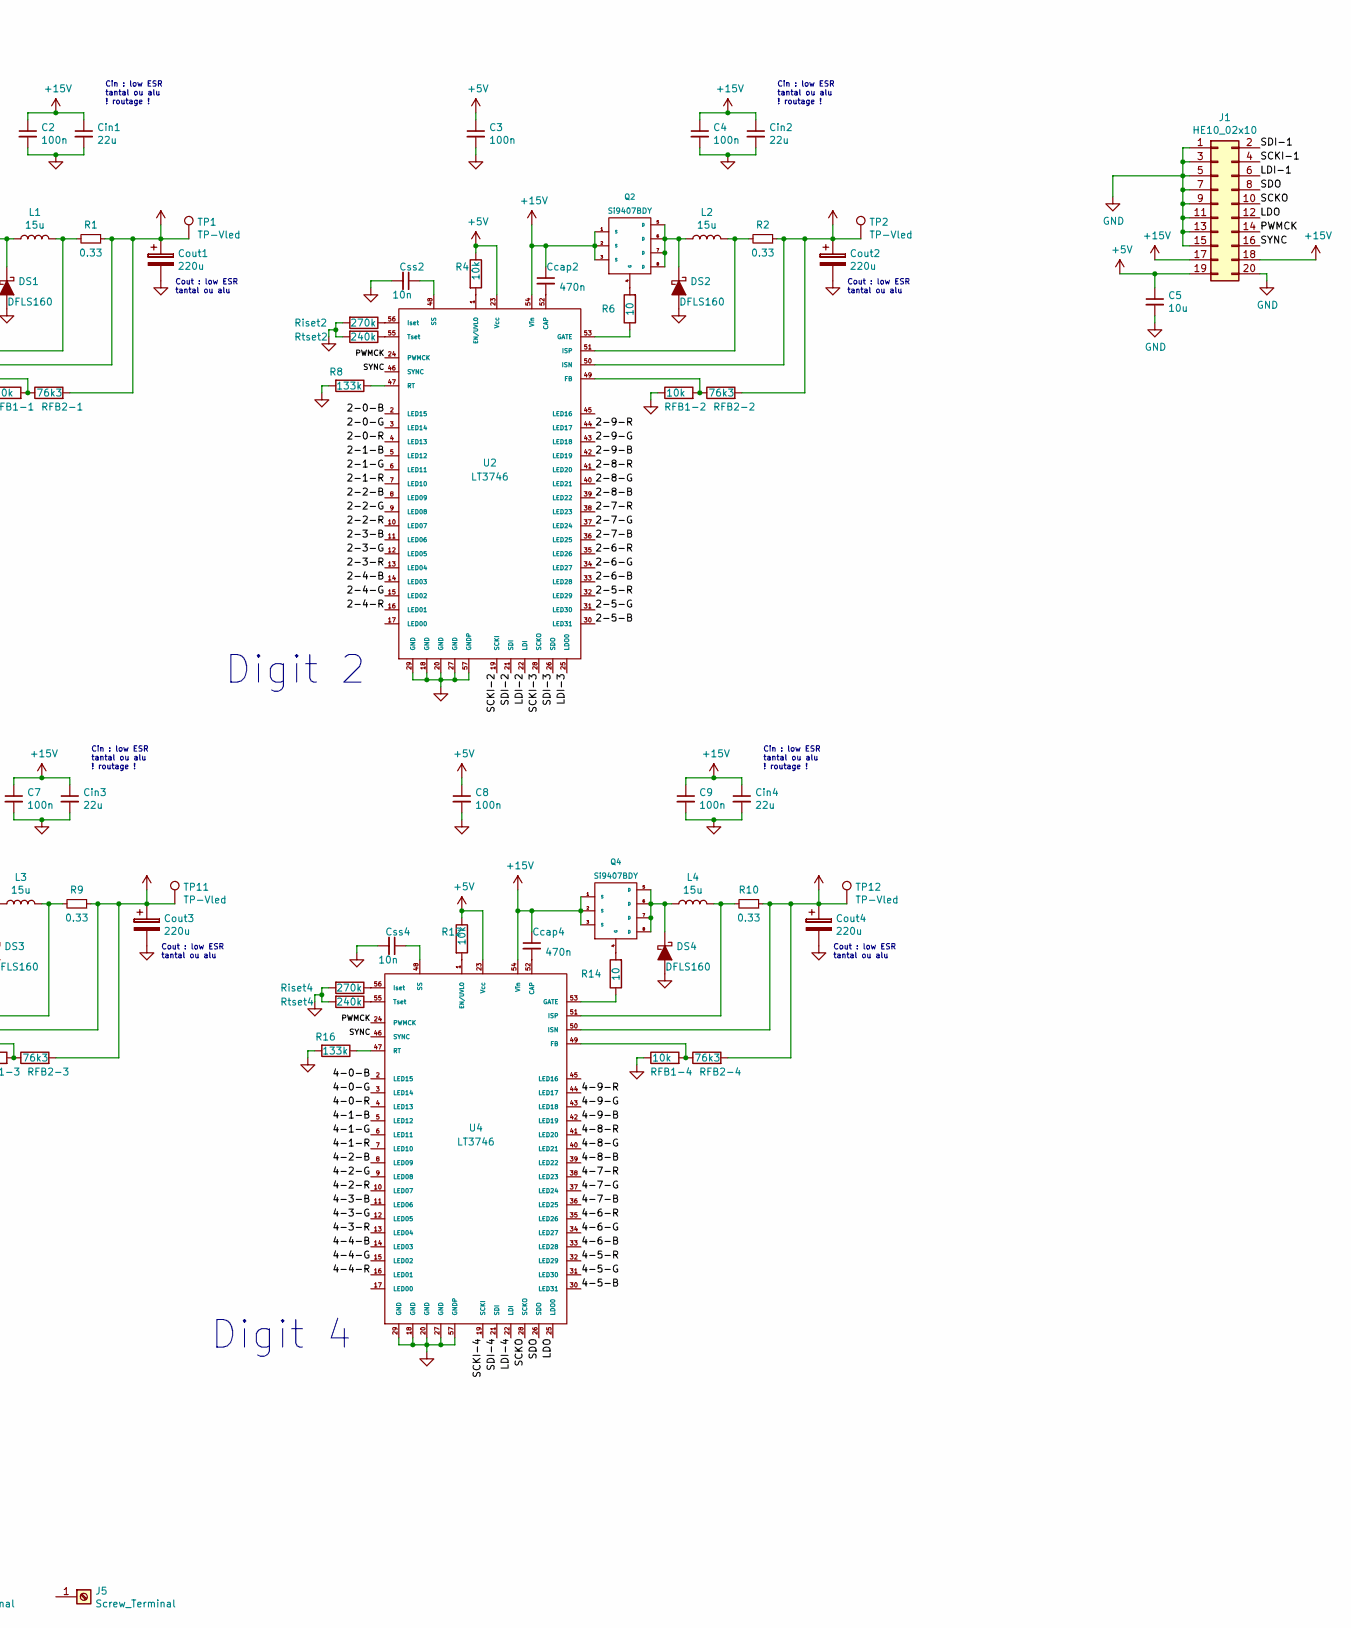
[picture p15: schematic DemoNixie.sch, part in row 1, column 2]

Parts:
C1, C2, C3, C4, C6, C7, C8, C9: 100n; C_0603_1608Metric_Pad1.05x0.95mm_HandSolder
C5: 10u; CP_Elec_6.3x5.9
Ccap1, Ccap2, Ccap3, Ccap4: 470n; C_0603_1608Metric_Pad1.05x0.95mm_HandSolder
Cin1, Cin2, Cin3, Cin4: 22u; CP_Elec_6.3x5.4
Cout1, Cout2, Cout3, Cout4: 220u; CP_Elec_10x14.3
Css1, Css2, Css3, Css4: 10n; C_0603_1608Metric_Pad1.05x0.95mm_HandSolder
D1, D2, D3, D4, D5, D6, D7, D8, D11, D12, D13, D14, D15, D16, D17, D18, D19, D20, D21, D22, D23, D24, D25, D26, D27, D28, D29, D30, D33, D34, D35, D36, D37, D38, D39, D40, D41, D42, D43, D44: WL-SFCC
DS1, DS2, DS3, DS4: DFLS160
J1: HE10_02x10; HE10_2x10_P2.54mm
J2, J3, J4, J5: Screw_Terminal; screwHole3.1mm
L1, L2, L3, L4: 15u; SLF7045-TDK
Q1, Q2, Q3, Q4: Si9407BDY; SOIC-8_3.9x4.9mm_P1.27mm
R1, R2, R9, R10: 0.33; R_0603_1608Metric_Pad1.05x0.95mm_HandSolder
R3, R4, R11, R12: 10k; R_0603_1608Metric_Pad1.05x0.95mm_HandSolder
R5, R6, R13, R14: 10; R_0603_1608Metric_Pad1.05x0.95mm_HandSolder
R7, R8, R15, R16: 133k; R_0603_1608Metric_Pad1.05x0.95mm_HandSolder
RFB1-1, RFB1-2, RFB1-3, RFB1-4: 10k; R_0603_1608Metric_Pad1.05x0.95mm_HandSolder
RFB2-1, RFB2-2, RFB2-3, RFB2-4: 76k3; R_0603_1608Metric_Pad1.05x0.95mm_HandSolder
Riset1, Riset2, Riset3, Riset4: 270k; R_0603_1608Metric_Pad1.05x0.95mm_HandSolder
Rtset1, Rtset2, Rtset3, Rtset4: 240k; R_0603_1608Metric_Pad1.05x0.95mm_HandSolder
TP1, TP2, TP11, TP12: TP-Vled; TestPoint_Pad_D1.5mm
U1, U2, U3, U4: LT3746; LT3746EUHH-TRPBF

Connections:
+5V: C1.1, C3.1, C5.1, C6.1, C8.1, J1.19, R3.1, R4.1, R11.1, R12.1, U1.23 (Vcc), U2.23 (Vcc), U3.23 (Vcc), U4.23 (Vcc)
+15V: C2.1, C4.1, C7.1, C9.1, Ccap1.1, Ccap2.1, Ccap3.1, Ccap4.1, Cin1.1, Cin2.1, Cin3.1, Cin4.1, J1.17, J1.18, Q1.1 (S), Q1.2 (S), Q1.3 (S), Q2.1 (S), Q2.2 (S), Q2.3 (S), Q3.1 (S), Q3.2 (S), Q3.3 (S), Q4.1 (S), Q4.2 (S), Q4.3 (S), U1.54 (Vin), U2.54 (Vin), U3.54 (Vin), U4.54 (Vin)
/1-0-B: D1.4 (B), U1.2 (LED15)
/1-0-G: D1.3 (G), U1.3 (LED14)
/1-0-R: D1.2 (R), U1.4 (LED13)
/1-1-B: D5.4 (B), U1.5 (LED12)
/1-1-G: D5.3 (G), U1.6 (LED11)
/1-1-R: D5.2 (R), U1.7 (LED10)
/1-2-B: D11.4 (B), U1.8 (LED09)
/1-2-G: D11.3 (G), U1.9 (LED08)
/1-2-R: D11.2 (R), U1.10 (LED07)
/1-3-B: D15.4 (B), U1.11 (LED06)
/1-3-G: D15.3 (G), U1.12 (LED05)
/1-3-R: D15.2 (R), U1.13 (LED04)
/1-4-B: D19.4 (B), U1.14 (LED03)
/1-4-G: D19.3 (G), U1.15 (LED02)
/1-4-R: D19.2 (R), U1.16 (LED01)
/1-5-B: D23.4 (B), U1.30 (LED31)
/1-5-G: D23.3 (G), U1.31 (LED30)
/1-5-R: D23.2 (R), U1.32 (LED29)
/1-6-B: D27.4 (B), U1.33 (LED28)
/1-6-G: D27.3 (G), U1.34 (LED27)
/1-6-R: D27.2 (R), U1.35 (LED26)
/1-7-B: D33.4 (B), U1.36 (LED25)
/1-7-G: D33.3 (G), U1.37 (LED24)
/1-7-R: D33.2 (R), U1.38 (LED23)
/1-8-B: D37.4 (B), U1.39 (LED22)
/1-8-G: D37.3 (G), U1.40 (LED21)
/1-8-R: D37.2 (R), U1.41 (LED20)
/1-9-B: D41.4 (B), U1.42 (LED19)
/1-9-G: D41.3 (G), U1.43 (LED18)
/1-9-R: D41.2 (R), U1.44 (LED17)
/2-0-B: D2.4 (B), U2.2 (LED15)
/2-0-G: D2.3 (G), U2.3 (LED14)
/2-0-R: D2.2 (R), U2.4 (LED13)
/2-1-B: D6.4 (B), U2.5 (LED12)
/2-1-G: D6.3 (G), U2.6 (LED11)
/2-1-R: D6.2 (R), U2.7 (LED10)
/2-2-B: D12.4 (B), U2.8 (LED09)
/2-2-G: D12.3 (G), U2.9 (LED08)
/2-2-R: D12.2 (R), U2.10 (LED07)
/2-3-B: D16.4 (B), U2.11 (LED06)
/2-3-G: D16.3 (G), U2.12 (LED05)
/2-3-R: D16.2 (R), U2.13 (LED04)
/2-4-B: D20.4 (B), U2.14 (LED03)
/2-4-G: D20.3 (G), U2.15 (LED02)
/2-4-R: D20.2 (R), U2.16 (LED01)
/2-5-B: D24.4 (B), U2.30 (LED31)
/2-5-G: D24.3 (G), U2.31 (LED30)
/2-5-R: D24.2 (R), U2.32 (LED29)
/2-6-B: D28.4 (B), U2.33 (LED28)
/2-6-G: D28.3 (G), U2.34 (LED27)
/2-6-R: D28.2 (R), U2.35 (LED26)
/2-7-B: D34.4 (B), U2.36 (LED25)
/2-7-G: D34.3 (G), U2.37 (LED24)
/2-7-R: D34.2 (R), U2.38 (LED23)
/2-8-B: D38.4 (B), U2.39 (LED22)
/2-8-G: D38.3 (G), U2.40 (LED21)
/2-8-R: D38.2 (R), U2.41 (LED20)
/2-9-B: D42.4 (B), U2.42 (LED19)
/2-9-G: D42.3 (G), U2.43 (LED18)
/2-9-R: D42.2 (R), U2.44 (LED17)
/3-0-B: D3.4 (B), U3.2 (LED15)
/3-0-G: D3.3 (G), U3.3 (LED14)
/3-0-R: D3.2 (R), U3.4 (LED13)
/3-1-B: D7.4 (B), U3.5 (LED12)
/3-1-G: D7.3 (G), U3.6 (LED11)
/3-1-R: D7.2 (R), U3.7 (LED10)
/3-2-B: D13.4 (B), U3.8 (LED09)
/3-2-G: D13.3 (G), U3.9 (LED08)
/3-2-R: D13.2 (R), U3.10 (LED07)
/3-3-B: D17.4 (B), U3.11 (LED06)
/3-3-G: D17.3 (G), U3.12 (LED05)
/3-3-R: D17.2 (R), U3.13 (LED04)
/3-4-B: D21.4 (B), U3.14 (LED03)
/3-4-G: D21.3 (G), U3.15 (LED02)
/3-4-R: D21.2 (R), U3.16 (LED01)
/3-5-B: D25.4 (B), U3.30 (LED31)
/3-5-G: D25.3 (G), U3.31 (LED30)
/3-5-R: D25.2 (R), U3.32 (LED29)
/3-6-B: D29.4 (B), U3.33 (LED28)
/3-6-G: D29.3 (G), U3.34 (LED27)
/3-6-R: D29.2 (R), U3.35 (LED26)
/3-7-B: D35.4 (B), U3.36 (LED25)
/3-7-G: D35.3 (G), U3.37 (LED24)
/3-7-R: D35.2 (R), U3.38 (LED23)
/3-8-B: D39.4 (B), U3.39 (LED22)
/3-8-G: D39.3 (G), U3.40 (LED21)
/3-8-R: D39.2 (R), U3.41 (LED20)
/3-9-B: D43.4 (B), U3.42 (LED19)
/3-9-G: D43.3 (G), U3.43 (LED18)
/3-9-R: D43.2 (R), U3.44 (LED17)
/4-0-B: D4.4 (B), U4.2 (LED15)
/4-0-G: D4.3 (G), U4.3 (LED14)
/4-0-R: D4.2 (R), U4.4 (LED13)
/4-1-B: D8.4 (B), U4.5 (LED12)
/4-1-G: D8.3 (G), U4.6 (LED11)
/4-1-R: D8.2 (R), U4.7 (LED10)
/4-2-B: D14.4 (B), U4.8 (LED09)
/4-2-G: D14.3 (G), U4.9 (LED08)
/4-2-R: D14.2 (R), U4.10 (LED07)
/4-3-B: D18.4 (B), U4.11 (LED06)
/4-3-G: D18.3 (G), U4.12 (LED05)
/4-3-R: D18.2 (R), U4.13 (LED04)
/4-4-B: D22.4 (B), U4.14 (LED03)
/4-4-G: D22.3 (G), U4.15 (LED02)
/4-4-R: D22.2 (R), U4.16 (LED01)
/4-5-B: D26.4 (B), U4.30 (LED31)
/4-5-G: D26.3 (G), U4.31 (LED30)
/4-5-R: D26.2 (R), U4.32 (LED29)
/4-6-B: D30.4 (B), U4.33 (LED28)
/4-6-G: D30.3 (G), U4.34 (LED27)
/4-6-R: D30.2 (R), U4.35 (LED26)
/4-7-B: D36.4 (B), U4.36 (LED25)
/4-7-G: D36.3 (G), U4.37 (LED24)
/4-7-R: D36.2 (R), U4.38 (LED23)
/4-8-B: D40.4 (B), U4.39 (LED22)
/4-8-G: D40.3 (G), U4.40 (LED21)
/4-8-R: D40.2 (R), U4.41 (LED20)
/4-9-B: D44.4 (B), U4.42 (LED19)
/4-9-G: D44.3 (G), U4.43 (LED18)
/4-9-R: D44.2 (R), U4.44 (LED17)
/LDI-1: J1.6, U1.22 (LDI)
/LDI-2: U1.25 (LDO0), U2.22 (LDI)
/LDI-3: U2.25 (LDO0), U3.22 (LDI)
/LDI-4: U3.25 (LDO0), U4.22 (LDI)
/LDO: J1.12, U4.25 (LDO0)
/PWMCK: J1.14, U1.24 (PWMCK), U2.24 (PWMCK), U3.24 (PWMCK), U4.24 (PWMCK)
/SCKI-1: J1.4, U1.19 (SCKI)
/SCKI-2: U1.28 (SCKO), U2.19 (SCKI)
/SCKI-3: U2.28 (SCKO), U3.19 (SCKI)
/SCKI-4: U3.28 (SCKO), U4.19 (SCKI)
/SCKO: J1.10, U4.28 (SCKO)
/SDI-1: J1.2, U1.21 (SDI)
/SDI-2: U1.26 (SDO), U2.21 (SDI)
/SDI-3: U2.26 (SDO), U3.21 (SDI)
/SDI-4: U3.26 (SDO), U4.21 (SDI)
/SDO: J1.8, U4.26 (SDO)
/SYNC: J1.16, U1.46 (SYNC), U2.46 (SYNC), U3.46 (SYNC), U4.46 (SYNC)
GND: C1.2, C2.2, C3.2, C4.2, C5.2, C6.2, C7.2, C8.2, C9.2, Cin1.2, Cin2.2, Cin3.2, Cin4.2, Cout1.2, Cout2.2, Cout3.2, Cout4.2, Css1.2, Css2.2, Css3.2, Css4.2, DS1.2 (A), DS2.2 (A), DS3.2 (A), DS4.2 (A), J1.1, J1.3, J1.5, J1.7, J1.9, J1.11, J1.13, J1.15, J1.20, R7.2, R8.2, R15.2, R16.2, RFB1-1.1, RFB1-2.1, RFB1-3.1, RFB1-4.1, Riset1.2, Riset2.2, Riset3.2, Riset4.2, Rtset1.2, Rtset2.2, Rtset3.2, Rtset4.2, U1.18 (GND), U1.20 (GND), U1.27 (GND), U1.29 (GND), U1.57 (GNDP), U2.18 (GND), U2.20 (GND), U2.27 (GND), U2.29 (GND), U2.57 (GNDP), U3.18 (GND), U3.20 (GND), U3.27 (GND), U3.29 (GND), U3.57 (GNDP), U4.18 (GND), U4.20 (GND), U4.27 (GND), U4.29 (GND), U4.57 (GNDP)
unnamed: Ccap1.2, U1.52 (CAP)
unnamed: Ccap2.2, U2.52 (CAP)
unnamed: Ccap3.2, U3.52 (CAP)
unnamed: Ccap4.2, U4.52 (CAP)
unnamed: Css1.1, U1.48 (SS)
unnamed: Css2.1, U2.48 (SS)
unnamed: Css3.1, U3.48 (SS)
unnamed: Css4.1, U4.48 (SS)
unnamed: DS1.1 (K), L1.1, Q1.5 (D), Q1.6 (D), Q1.7 (D), Q1.8 (D)
unnamed: DS2.1 (K), L2.1, Q2.5 (D), Q2.6 (D), Q2.7 (D), Q2.8 (D)
unnamed: DS3.1 (K), L3.1, Q3.5 (D), Q3.6 (D), Q3.7 (D), Q3.8 (D)
unnamed: DS4.1 (K), L4.1, Q4.5 (D), Q4.6 (D), Q4.7 (D), Q4.8 (D)
unnamed: L1.2, R1.2, U1.51 (ISP)
unnamed: L2.2, R2.2, U2.51 (ISP)
unnamed: L3.2, R9.2, U3.51 (ISP)
unnamed: L4.2, R10.2, U4.51 (ISP)
unnamed: Q1.4 (G), R5.2
unnamed: Q2.4 (G), R6.2
unnamed: Q3.4 (G), R13.2
unnamed: Q4.4 (G), R14.2
unnamed: R3.2, U1.1 (EN/UVLO)
unnamed: R4.2, U2.1 (EN/UVLO)
unnamed: R5.1, U1.53 (GATE)
unnamed: R6.1, U2.53 (GATE)
unnamed: R7.1, U1.47 (RT)
unnamed: R8.1, U2.47 (RT)
unnamed: R11.2, U3.1 (EN/UVLO)
unnamed: R12.2, U4.1 (EN/UVLO)
unnamed: R13.1, U3.53 (GATE)
unnamed: R14.1, U4.53 (GATE)
unnamed: R15.1, U3.47 (RT)
unnamed: R16.1, U4.47 (RT)
unnamed: RFB1-1.2, RFB2-1.1, U1.49 (FB)
unnamed: RFB1-2.2, RFB2-2.1, U2.49 (FB)
unnamed: RFB1-3.2, RFB2-3.1, U3.49 (FB)
unnamed: RFB1-4.2, RFB2-4.1, U4.49 (FB)
unnamed: Riset1.1, U1.56 (Iset)
unnamed: Riset2.1, U2.56 (Iset)
unnamed: Riset3.1, U3.56 (Iset)
unnamed: Riset4.1, U4.56 (Iset)
unnamed: Rtset1.1, U1.55 (Tset)
unnamed: Rtset2.1, U2.55 (Tset)
unnamed: Rtset3.1, U3.55 (Tset)
unnamed: Rtset4.1, U4.55 (Tset)
VPP: Cout1.1, Cout2.1, Cout3.1, Cout4.1, D1.1 (A), D2.1 (A), D3.1 (A), D4.1 (A), D5.1 (A), D6.1 (A), D7.1 (A), D8.1 (A), D11.1 (A), D12.1 (A), D13.1 (A), D14.1 (A), D15.1 (A), D16.1 (A), D17.1 (A), D18.1 (A), D19.1 (A), D20.1 (A), D21.1 (A), D22.1 (A), D23.1 (A), D24.1 (A), D25.1 (A), D26.1 (A), D27.1 (A), D28.1 (A), D29.1 (A), D30.1 (A), D33.1 (A), D34.1 (A), D35.1 (A), D36.1 (A), D37.1 (A), D38.1 (A), D39.1 (A), D40.1 (A), D41.1 (A), D42.1 (A), D43.1 (A), D44.1 (A), R1.1, R2.1, R9.1, R10.1, RFB2-1.2, RFB2-2.2, RFB2-3.2, RFB2-4.2, TP1.1, TP2.1, TP11.1, TP12.1, U1.50 (ISN), U2.50 (ISN), U3.50 (ISN), U4.50 (ISN)

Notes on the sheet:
Digit 1
Digit 2
Digit 3
Digit 4
Digit-Ligne-Couleur
Cout : low ESR tantal ou alu
Cin : low ESR tantal ou alu ! routage !

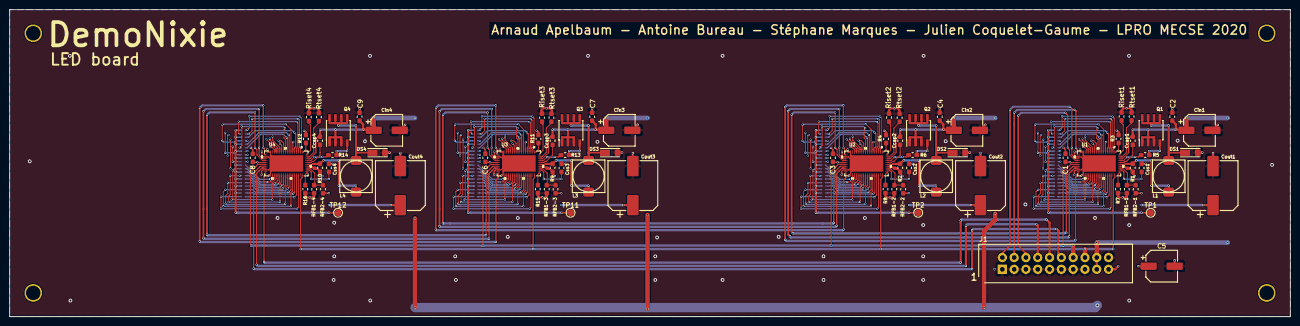
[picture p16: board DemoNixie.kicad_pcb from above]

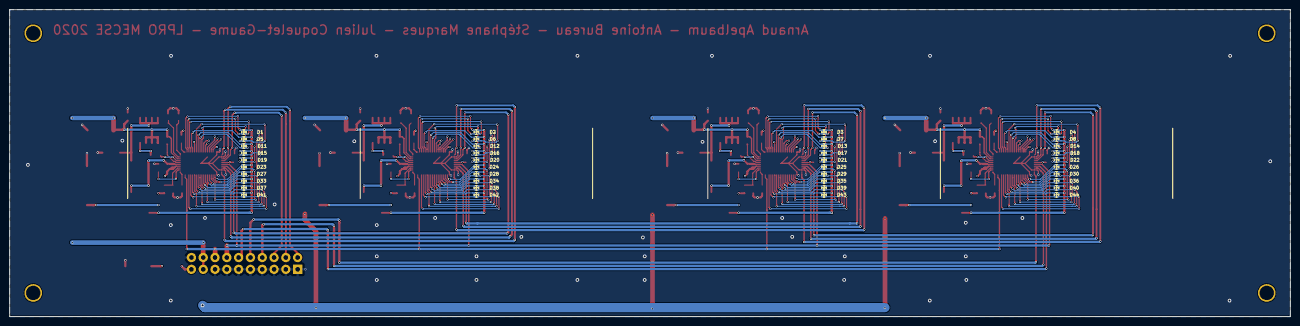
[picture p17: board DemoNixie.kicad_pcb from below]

Board: 4 copper layers, 275.6 x 66.0 mm, 122 parts (40 on the bottom side), 185 nets.

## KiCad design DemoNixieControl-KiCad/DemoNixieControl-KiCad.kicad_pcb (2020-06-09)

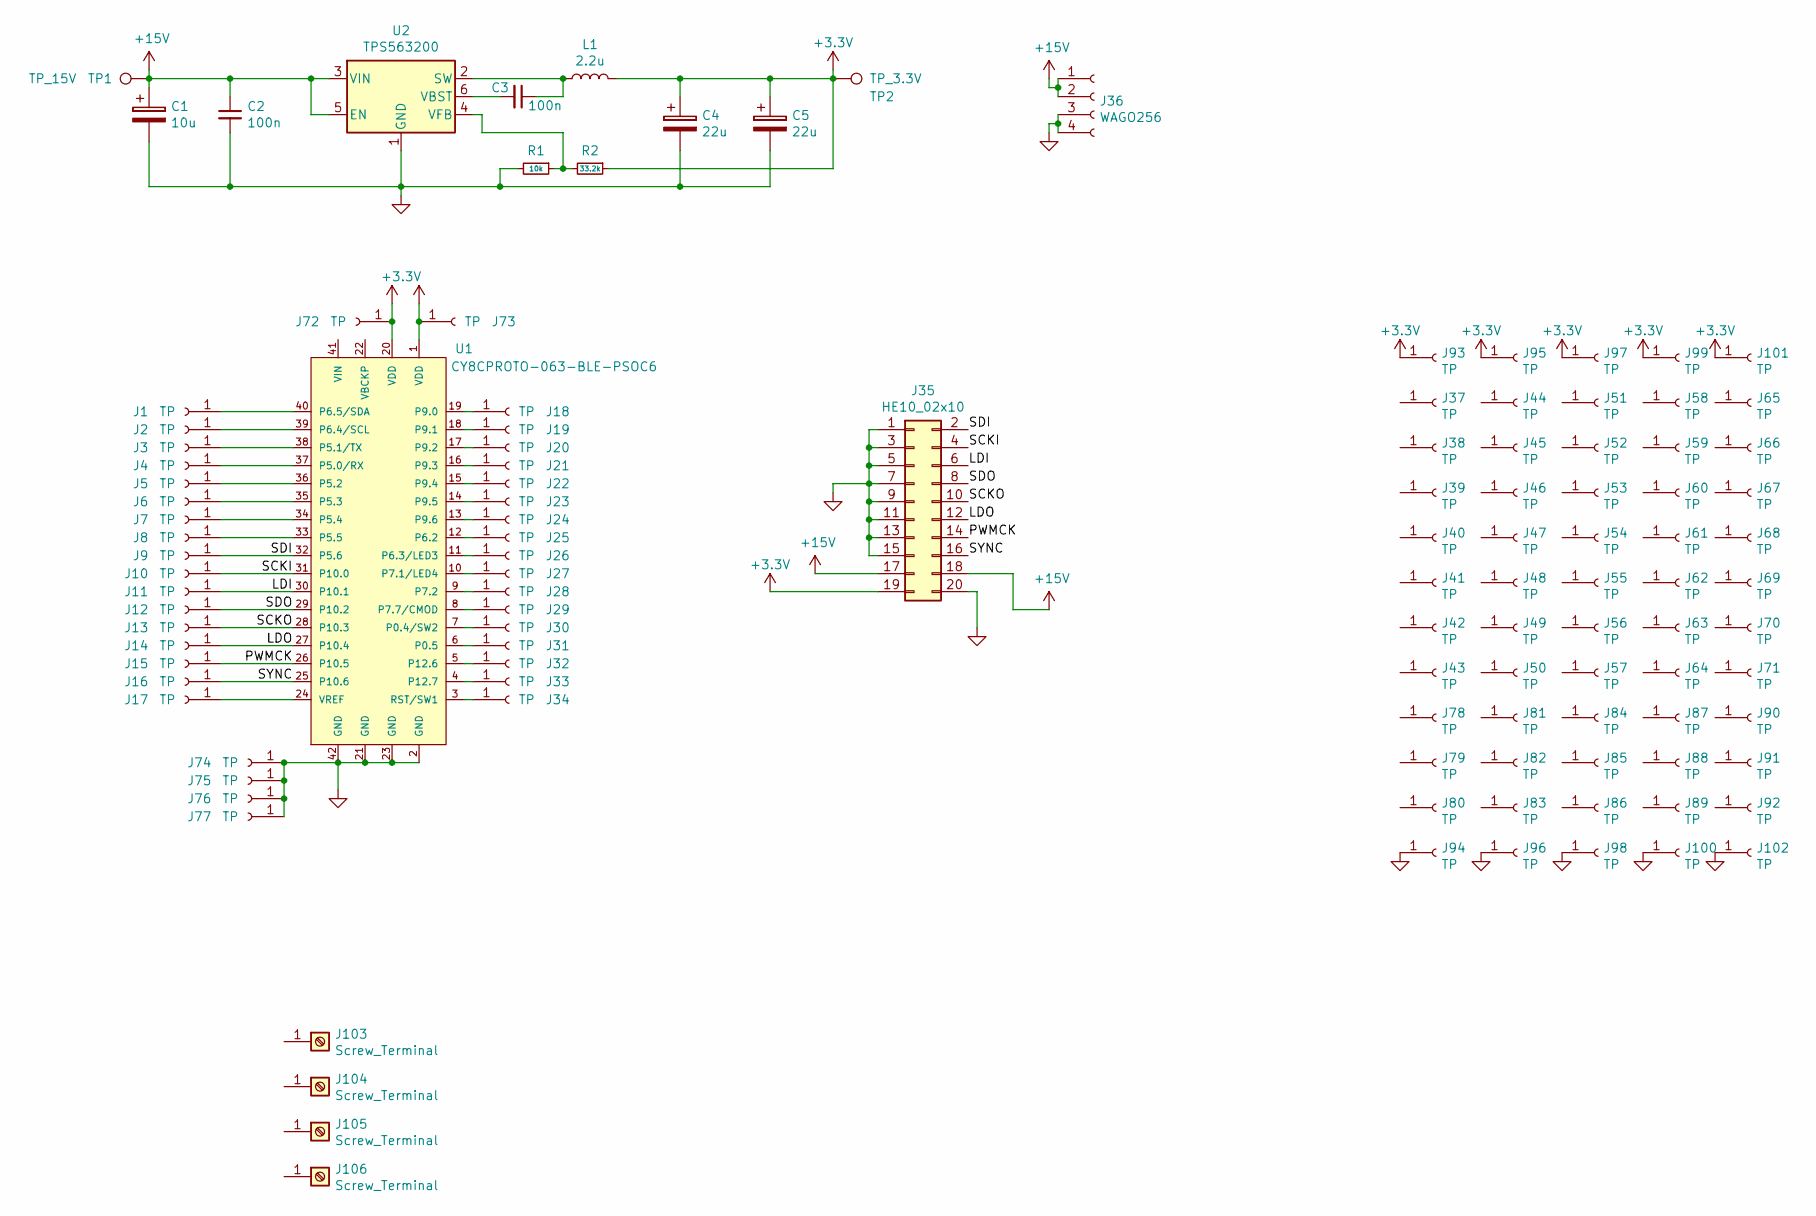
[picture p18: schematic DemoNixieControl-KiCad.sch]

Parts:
C1: 10u; CP_Elec_6.3x5.9
C2, C3: 100n; C_0603_1608Metric_Pad1.05x0.95mm_HandSolder
C4, C5: 22u; CP_Elec_6.3x5.4
J1, J2, J3, J4, J5, J6, J7, J8, J9, J10, J11, J12, J13, J14, J15, J16, J17, J18, J19, J20, J21, J22, J23, J24, J25, J26, J27, J28, J29, J30, J31, J32, J33, J34, J37, J38, J39, J40, J41, J42, J43, J44, J45, J46, J47, J48, J49, J50, J51, J52, J53, J54, J55, J56, J57, J58, J59, J60, J61, J62, J63, J64, J65, J66, J67, J68, J69, J70, J71, J72, J73, J74, J75, J76, J77, J78, J79, J80, J81, J82, J83, J84, J85, J86, J87, J88, J89, J90, J91, J92, J93, J94, J95, J96, J97, J98, J99, J100, J101, J102: TP; PIN-tr1-d2
J35: HE10_02x10; HE10_2x10_P2.54mm
J36: WAGO256; WAGO-256-402
J103, J104, J105, J106: Screw_Terminal; screwHole3.1mm
L1: 2.2u; 744778002 Wurth
R1: 10k; R_0603_1608Metric_Pad1.05x0.95mm_HandSolder
R2: 33.2k; R_1206_3216Metric_Pad1.42x1.75mm_HandSolder
TP1: TP_15V; TestPoint_Loop_D1.80mm_Drill1.0mm_Beaded
TP2: TP_3.3V; TestPoint_Loop_D1.80mm_Drill1.0mm_Beaded
U1: CY8CPROTO-063-BLE-PSOC6; CY8CPROTO-063-BLE
U2: TPS563200; SOT-23-6_Handsoldering

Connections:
+3V3: C4.1, C5.1, J35.19, J72.1, J73.1, J93.1, J95.1, J97.1, J99.1, J101.1, L1.2, R2.1, TP2.1, U1.1 (VDD), U1.20 (VDD)
+15V: C1.1, C2.1, J35.17, J35.18, J36.1, J36.2, TP1.1, U2.3 (VIN), U2.5 (EN)
/LDI: J11.1, J35.6, U1.30 (P10.1)
/LDO: J14.1, J35.12, U1.27 (P10.4)
/PWMCK: J15.1, J35.14, U1.26 (P10.5)
/SCKI: J10.1, J35.4, U1.31 (P10.0)
/SCKO: J13.1, J35.10, U1.28 (P10.3)
/SDI: J9.1, J35.2, U1.32 (P5.6)
/SDO: J12.1, J35.8, U1.29 (P10.2)
/SYNC: J16.1, J35.16, U1.25 (P10.6)
GND: C1.2, C2.2, C4.2, C5.2, J35.1, J35.3, J35.5, J35.7, J35.9, J35.11, J35.13, J35.15, J35.20, J36.3, J36.4, J74.1, J75.1, J76.1, J77.1, J94.1, J96.1, J98.1, J100.1, J102.1, R1.2, U1.2 (GND), U1.21 (GND), U1.23 (GND), U1.42 (GND), U2.1 (GND)
unnamed: C3.1, L1.1, U2.2 (SW)
unnamed: C3.2, U2.6 (VBST)
unnamed: J1.1, U1.40 (P6.5/SDA)
unnamed: J2.1, U1.39 (P6.4/SCL)
unnamed: J3.1, U1.38 (P5.1/TX)
unnamed: J4.1, U1.37 (P5.0/RX)
unnamed: J5.1, U1.36 (P5.2)
unnamed: J6.1, U1.35 (P5.3)
unnamed: J7.1, U1.34 (P5.4)
unnamed: J8.1, U1.33 (P5.5)
unnamed: J17.1, U1.24 (VREF)
unnamed: J18.1, U1.19 (P9.0)
unnamed: J19.1, U1.18 (P9.1)
unnamed: J20.1, U1.17 (P9.2)
unnamed: J21.1, U1.16 (P9.3)
unnamed: J22.1, U1.15 (P9.4)
unnamed: J23.1, U1.14 (P9.5)
unnamed: J24.1, U1.13 (P9.6)
unnamed: J25.1, U1.12 (P6.2)
unnamed: J26.1, U1.11 (P6.3/LED3)
unnamed: J27.1, U1.10 (P7.1/LED4)
unnamed: J28.1, U1.9 (P7.2)
unnamed: J29.1, U1.8 (P7.7/CMOD)
unnamed: J30.1, U1.7 (P0.4/SW2)
unnamed: J31.1, U1.6 (P0.5)
unnamed: J32.1, U1.5 (P12.6)
unnamed: J33.1, U1.4 (P12.7)
unnamed: J34.1, U1.3 (RST/SW1)
unnamed: R1.1, R2.2, U2.4 (VFB)

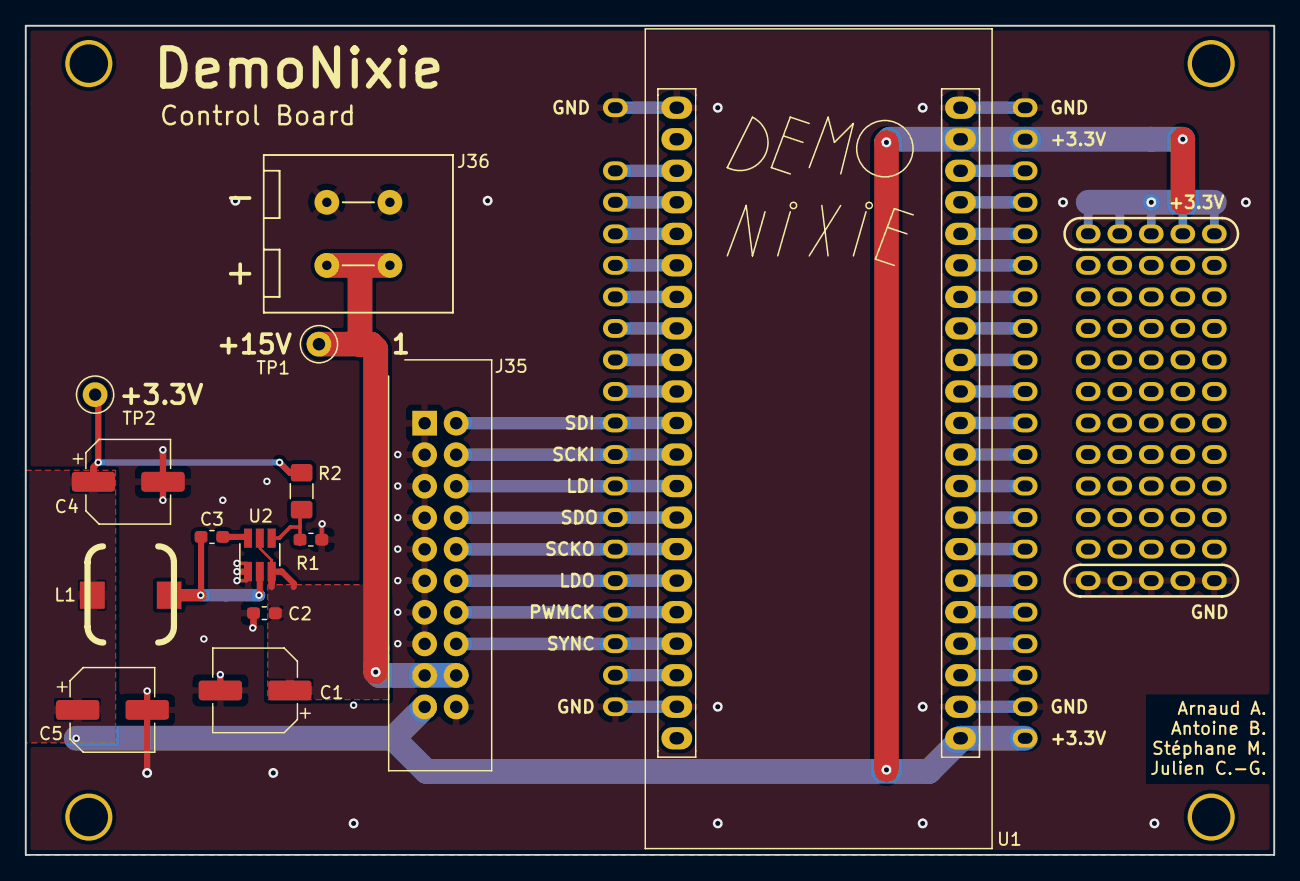
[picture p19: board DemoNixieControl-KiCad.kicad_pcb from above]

Board: 2 copper layers, 100.6 x 66.8 mm, 118 parts (0 on the bottom side), 40 nets.

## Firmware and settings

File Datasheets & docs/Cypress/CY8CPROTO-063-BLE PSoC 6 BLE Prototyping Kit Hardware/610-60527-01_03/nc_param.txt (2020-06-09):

INTEGER-PLACES         2
DECIMAL-PLACES         5
X-OFFSET               0.000000
Y-OFFSET               0.000000
FEEDRATE               1
COORDINATES            ABSOLUTE
OUTPUT-UNITS           ENGLISH
TOOL-ORDER             INCREASING
REPEAT-CODES           YES
SUPPRESS-LEAD-ZEROES   NO
SUPPRESS-TRAIL-ZEROES  NO
SUPPRESS-EQUAL         YES
TOOL-SELECT            YES
OPTIMIZE_DRILLING      YES
ENHANCED_EXCELLON      YES
HEADER                 CYPRESS^SEMICONDUCTOR
LEADER                 12
CODE                   ASCII
SEPARATE               NO
SEPARATE-ROUTING       NO
DRILLING               LAYER-PAIR
BACKDRILL              YES
CAVITY                 NO

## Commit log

2020-02-27 added led
2020-02-27 add led doc
2020-02-27 Add files via upload
    Score scrum et répartition des sprints
    [scrumPoker.xlsx]
2020-05-11 Retrait des documents et des exemples de codes qui sont transférés sur les bracnhes 'documents_divers' et 'exemples_de_codes'
    [scrumPoker.xlsx]
2020-05-11 Retrait du dossier DemoNixie transféré sur la branche 'exemples_de_codes'
2020-05-11 Update README.md
    MàJ infos sur les nouvelles branches
2020-05-11 Update README.md
    Ajout des sauts de ligne manquants
2020-06-09 creation de la branche
    [600-60527-01_03.brd, CY8CPROTO-063-BLE Layout.brd, CY8CPROTO-063-BLE Schematic.DSN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]
2020-06-09 finalisation controlBoard
    [DemoNixie v2 FINAL?.kicad_pcb, DemoNixie.kicad_pcb, DemoNixieControl-KiCad.kicad_pcb]
2020-06-10 ajout des cotes des cartes
    [DemoNixie-B.Cu.gbr, DemoNixie-B.Mask.gbr, DemoNixie-B.Paste.gbr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]
2020-06-15 ajout fichier de commande RS
    [DemoNixie.sch, commandeRS.ods, materiel.ods]

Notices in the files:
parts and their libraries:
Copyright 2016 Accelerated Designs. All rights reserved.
